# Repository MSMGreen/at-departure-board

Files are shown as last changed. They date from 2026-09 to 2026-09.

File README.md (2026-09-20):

# AT Departure Board



An ESP32 + 2.8" TFT that shows when the next bus and train actually leave, using
Auckland Transport's realtime feed.

Each service gets a lane, and the vehicle's position along its lane **is** its
time to arrival — it enters at the left twenty minutes out and pulls into the
stop as the countdown reaches zero. The point is that you can read it from
across a room without resolving any digits.

Status: live data, and configurable from a browser. The board fetches real AT
departures and realtime delays over WiFi/TLS, draws the board from them at
15 fps, and serves a setup page on your LAN for choosing stops and themes.
`DEMO_MODE` (synthetic departures, no network) still builds and is useful for a
no-key bring-up.

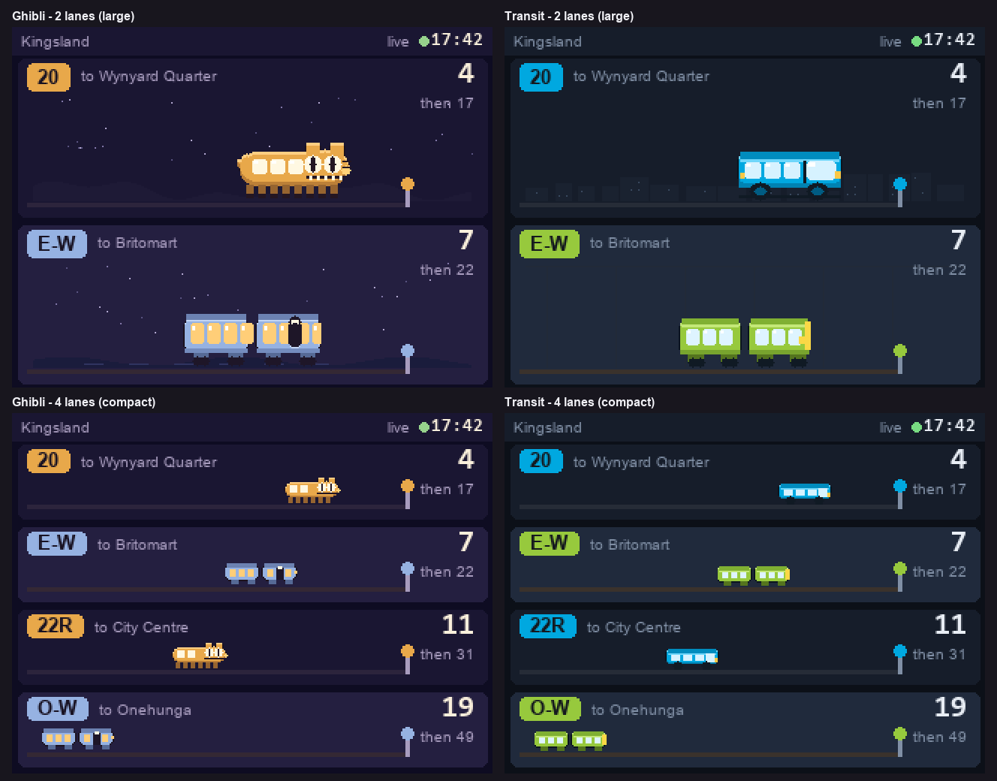
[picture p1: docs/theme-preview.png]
The board in two themes


## Try it without hardware

```bash
python -m pip install -r requirements-dev.txt
python tools/simulate.py --all --gif --show
```

Renders every board state to `tools/out/`, including the two that are easiest to
get wrong: 1am with nothing left tonight, and a cancelled service.

Two themes ship: `transit` and `ghibli`. Sprites come in two sizes — large art
at 1–2 watches, compact at 3–4, because a 40px vehicle does not fit a 55px lane.

```bash
python tools/simulate.py --scene two_up --theme ghibli
python tools/author_art.py               # regenerate the vehicle art
```

## Build one

Roughly an evening's work. **[docs/SETUP.md](docs/SETUP.md) is the full
walkthrough** — parts, wiring, flashing, and pointing it at your own stops. The
short version:

| Part | What to get |
|---|---|
| Board | Any standard **ESP32 DevKit (WROOM-32)**. The unit here is an ESP32-D0WD-V3: 4 MB flash, no PSRAM, CH340 USB-serial |
| Display | 2.8" 320x240 SPI panel, no touch needed — [the one used here](https://www.aliexpress.com/item/1005004557916570.html). Sold as ILI9341; the unit received was an **ST7789**, which the build flags already handle ([why](docs/hardware-notes.md)) |
| Case | Printed from `models/src/wedge.scad` in this repo — a raked wedge with a snap-on back. Dimensions for both boards in [docs/enclosure.md](docs/enclosure.md), assembly in [docs/assembly.md](docs/assembly.md) |
| Wiring | Nine jumper wires, or solder direct — table below |

You also need a free [AT developer API key](https://dev-portal.at.govt.nz/),
subscribed to **both** the GTFS and the Realtime products with the same key.

```bash
python -m pip install -r requirements-dev.txt
pio test -e native                       # firmware logic, on your PC (needs a C++ compiler)
cp src/secrets.example.h src/secrets.h   # then fill in WiFi + AT key
pio run -e esp32 -t upload               # the live board
pio run -e esp32_demo -t upload          # the demo: no WiFi, no API key
```

Before each upload: hold BOOT, tap EN, release BOOT. Auto-reset into the
bootloader does not work on these boards, and `platformio.ini` is set up
accordingly — see [docs/hardware-notes.md](docs/hardware-notes.md).

`platformio.ini` does not name a serial port, so PlatformIO auto-detects one. If
you have more than one board plugged in, pass it explicitly:

```bash
pio run -e esp32 -t upload --upload-port COM8      # /dev/ttyUSB0 on Linux
```

## Point it at your own stops

Once the board is on your WiFi, **open `http://<board-ip>/` in a browser** on the
same network. The setup page holds the location name, the theme, and up to four
watches. Save and restart writes them to NVS and reboots the board, which takes
a couple of seconds.

The board prints its IP to the serial monitor at boot (`pio device monitor`),
and it is also the new ESP32 client in your router's device list:

```
wifi: connected, ip 192.168.1.42 rssi -54
```

Each watch is four fields:

| Field | Meaning |
|---|---|
| Label | What the lane is called on the panel, e.g. `to Wynyard Quarter` (24 characters) |
| Stop code | The number on the pole, e.g. `8213`. **Check** confirms it against AT and shows you the stop's name |
| Route | A route to pin, e.g. `20`. Leave it empty for "any route that stops here" |
| Toward stop | The stop you are travelling *toward*, never a direction — direction is derived at every refresh ([why](docs/at-api-notes.md)) |

Pin a route when the stop also serves services you would never board: stop 8213
here is served by `22R`/`22N` as well, so that watch pins `20`. A stop served
only by routes you'd actually take can leave Route empty, as a rail watch does
— that is also what carries a rail watch through a line rename.

WiFi credentials and the API key are **not** in the setup page. They are
compiled in from `src/secrets.h`, which is gitignored, so changing networks
means a re-flash. `src/watch_config.h` holds the watches the board seeds NVS
with on its first boot, and is only consulted then.

### The setup page is unauthenticated

It is plain HTTP on port 80 with no password, so anyone on your LAN can change
the board's stops or reboot it. That is a deliberate trade for a device with no
keyboard on a home network — the page exposes no credentials and the board
stores nothing sensitive — but do not put this on an untrusted or guest
network, and do not forward a port to it.

## Development

```bash
python -m pytest                # the renderer and the tools
pio test -e native              # the firmware logic (needs a C++ compiler)
python tools/regolden.py        # ONLY when a render change is intended
python tools/export_sprites.py  # regenerate src/sprites.h after editing sprites
```

Renders are compared byte-exact against `tests/golden/`. A failing golden test
means the render changed — if that was intended, regenerate and commit the
goldens in the same commit as the change. Both suites run in CI on every push
and pull request. [CONTRIBUTING.md](CONTRIBUTING.md) has the rest.

## Layout

| Concern | File |
|---|---|
| Colour roles, AT `route_color` handling | `tools/board/palette.py` |
| Themes (palette, sprites, scenery) | `tools/board/themes/` |
| Vehicle art (parametric source) | `tools/author_art.py` |
| Pixel-art vehicles | `tools/board/sprites.py` |
| What the screen is showing | `tools/board/model.py` |
| Lane geometry, ETA → x position | `tools/board/layout.py` |
| Drawing | `tools/board/render.py` |
| The canonical board states | `tools/board/scenes.py` |
| Export sprites to C | `tools/export_sprites.py` |
| Firmware logic, no Arduino headers | `lib/core/src/` |
| Firmware wiring: network, portal, panel | `src/` |

Sprites are authored as role grids — `B` for body, `W` for window — rather than
literal colours, which is what lets one bus sprite render in whatever colour its
route is, and what lets a theme reinterpret every role at once. `src/sprites.h`
is generated from the same data and committed, so the firmware build never needs
Python.

Art is never typed by hand. Edit `tools/author_art.py`, which draws it
parametrically, then regenerate.

## Wiring

ESP32 dev board (WROOM-32) and a 2.8" 320x240 ST7789 SPI panel, no touch (sold as
ILI9341 — see `docs/hardware-notes.md`).

| Display | ESP32 |
|---|---|
| VCC | 3V3 |
| GND | GND |
| CS | GPIO15 |
| RESET | GPIO4 |
| DC / RS | GPIO2 |
| SDI / MOSI | GPIO23 |
| SCK | GPIO18 |
| LED | GPIO32 |
| SDO / MISO | GPIO19 |

Drive the backlight from GPIO32 rather than 3V3: there it is PWM-able, which is
what lets the panel dim rather than only switch off.

## Documentation

- [docs/SETUP.md](docs/SETUP.md) — build one from parts, start to finish.
- [docs/at-api-notes.md](docs/at-api-notes.md) — the AT API as it actually
  behaves, verified against live endpoints. **Read this before touching the
  network code**; it differs from AT's own documentation in five places,
  including one that would make the board re-resolve every stop every night.
- [docs/hardware-notes.md](docs/hardware-notes.md) — measured heap, the flashing
  dance, and why the panel is an ST7789.
- [docs/enclosure.md](docs/enclosure.md) — every dimension of the case and the
  two boards, and where each number came from.
- [docs/assembly.md](docs/assembly.md) — wiring and fitting it all into the
  printed case.
- [docs/design/](docs/design/) — the specs and implementation plans each
  feature was built from, kept as the record of why the code is shaped the way
  it is.

## Data and attribution

Departure data comes from [Auckland Transport's developer
API](https://dev-portal.at.govt.nz/) and is used under AT's developer terms —
check those terms before redistributing anything you build on it. The JSON under
`test/fixtures/` is captured AT API output, trimmed and used as test input.

This project is not affiliated with, endorsed by, or supported by Auckland
Transport.

## Licence

MIT — see `LICENSE`.

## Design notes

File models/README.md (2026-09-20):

# The enclosure

A raked wedge, 90 × 48 × 70 mm, in two printed parts: a body that holds the
panel and the DevKit, and a cover that snaps on the back.

```
src/wedge.scad          the model - every dimension is a named constant
build/wedge_body.stl    ready to slice
build/wedge_cover.stl   ready to slice
```

**To print one, take the two STLs in `build/`.** You do not need OpenSCAD for
that — they are committed for the same reason `src/sprites.h` is, so that
building the thing doesn't require the tool that generated it.

Print the body **on its back face**. The raked front then becomes a 15° overhang
that needs no support, and the face you look at comes out clean.

## To change it

`src/wedge.scad` is the source of truth. Case size, rake, wall thickness, panel
pocket, DevKit bay and every clearance are named constants at the top of the
file; change one and re-render:

```bash
openscad -o build/wedge_body.stl  -D 'part="body"'  src/wedge.scad
openscad -o build/wedge_cover.stl -D 'part="cover"' src/wedge.scad
```

Re-render and commit both STLs in the same commit as the `.scad` change, the
same rule the golden renders follow.

`python -m pytest tests/test_models.py` re-checks the clearances the design
depends on against the constants actually in the file, and that each part is
still a single manifold solid. It skips itself if OpenSCAD isn't installed.

## Where the numbers came from

[`../docs/enclosure.md`](../docs/enclosure.md) — every dimension of the case,
the panel and the DevKit, and the source of each (datasheet, measured, or
derived). [`../docs/assembly.md`](../docs/assembly.md) is how it goes together.
The reasoning behind the shape is in
[`../docs/design/specs/2026-09-20-enclosure-wedge-design.md`](../docs/design/specs/2026-09-20-enclosure-wedge-design.md).

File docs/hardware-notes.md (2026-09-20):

# Hardware and firmware notes — measured, not estimated

Everything here was measured on the actual board on 2026-09-15 by a throwaway
spike (`spike/heap/`, removed once it had answered its question — the code is
in the git history, last present at 026bc09). Where the design doc guessed a
number, the measured one is recorded next to it.

## The board

| | |
|---|---|
| Chip | ESP32-D0WD-V3 rev 3, dual core @ 240 MHz |
| Flash | 4 MB |
| PSRAM | **none** |
| USB-serial | CH340 (`1A86:7523`) |
| Shipped firmware | Espressif ESP-AT 1.1.2 — overwritten on first flash |

### Uploading needs the BOOT button held

Auto-reset into the bootloader does not work on this board: esptool resets the
chip but GPIO0 is not pulled low, so it boots the app and esptool reports
`Wrong boot mode detected (0x13)`.

What works reliably (2026-09-19): put the chip into download mode *first*, then
flash without letting esptool reset it.

1. Hold **BOOT**, press and release **EN**, then release **BOOT**. The chip now
   sits in the bootloader; the screen does not change.
2. `pio run -e esp32 -t upload`. `platformio.ini` sets
   `board_upload.before_reset = no_reset` and `upload_speed = 115200`, so
   esptool neither tries the broken auto-reset nor drops the link.

`--after hard_reset` via RTS *does* work, so the new firmware starts on its own.

Two ways it fails: `pio run -t upload` gives up after ~11 s, before a human can
do the buttons; and at **460800** baud the CH340 link drops right after the
baud switch (`No more data to read from the serial port`). Releasing BOOT
before EN also misses download mode (`No serial data received`).

Permanent fix if it becomes tiresome: a 1 µF capacitor between EN and GND.

## Memory — the design's budget holds with ~2x headroom

Paper estimate was ~85 KB of ~300 KB: 40 KB TLS + 35 KB sprite + 8 KB parser.

| Measurement | Value |
|---|---|
| Free heap at boot | 351,448 |
| **Largest contiguous block at boot** | **114,676** |
| 35,840-byte lane sprite | allocated, every byte touched |
| Free with sprite held | 315,592 |
| Free after WiFi up | ~209,000 |
| **TLS handshake cost** | **~44,000** (est. 40,000) |
| Free with sprite + TLS + parse live | ~157,000 |
| Largest block at that moment | 94,196 |
| **Lowest heap across a full run** | **150,932** |
| Leak check | returns to boot value exactly after every request |

### The per-lane sprite was necessary, not merely tidy

Free heap is ~351 KB but the **largest single block is ~114 KB**, because the
ESP32 heap is split across regions. A full-screen 320x240x16bpp framebuffer
needs **153,600 bytes contiguous** and therefore *cannot* be allocated at all.

The design's 320x56 per-lane sprite (35,840 bytes) was the only approach that
was ever going to work. Do not "optimise" it into a full framebuffer later.

## The display is an ST7789, not an ILI9341

The module is the common red "2.8\" TFT 240xRGBx320 V1.1" SPI board with an SD
slot and a touch footprint (touch unpopulated). It is sold as ILI9341, and the
design doc assumed that. The unit on hand has an **ST7789** controller. Found
by a bring-up spike (`spike/display/`, also removed — see the git history),
2026-09-19.

Wiring is exactly as in design doc §2, and it is right: nothing had to change.

TFT_eSPI configuration that works (build flags, no `User_Setup.h` edit):

```
-DUSER_SETUP_LOADED=1
-DST7789_DRIVER=1
-DTFT_RGB_ORDER=TFT_BGR
-DTFT_INVERSION_OFF=1
-DTFT_WIDTH=240  -DTFT_HEIGHT=320
-DTFT_MISO=19 -DTFT_MOSI=23 -DTFT_SCLK=18 -DTFT_CS=15 -DTFT_DC=2 -DTFT_RST=4
-DSPI_FREQUENCY=27000000
```

`setRotation(1)` and `(3)` give a clean 320x240 landscape; all four rotations
fill the glass edge to edge. The backlight on GPIO32 is driven HIGH by the app.

How each wrong setting looks, so it can be recognised again:

| Setting | Symptom |
|---|---|
| `ILI9341_DRIVER` | Landscape drawn un-rotated into 240 columns; the other 80 are static. Other rotations cut up / off-centre. Red and blue swapped. |
| ST7789, default inversion (ON) | Whole image a photo negative: black background shows white. |
| ST7789, default colour order (RGB) | Red and blue swapped. |
| Both defaults together | Red→yellow, green→magenta, blue→cyan, yellow→red. Looks random; it's inversion plus swap. |

The panel **does not answer reads**: RDDID (`0xD3`) returns `00 00 00` and
RDDST returns constant garbage. So the controller can't be detected in software;
identify it by rendering, as above. Don't build anything that depends on
reading back from the panel.

## Display performance

Measured on 2026-09-19 over a 225 s capture covering every scene in both themes,
SPI at 27 MHz (the default set in `platformio.ini`):

| Measurement | Value |
|---|---|
| SPI clock | 27 MHz |
| **Worst draw time per frame** | **59 ms** |
| Frame rate (all scenes) | 14.9–15.1 fps |
| **Lowest heap (min-ever)** | **311,588 bytes** |
| Largest contiguous block | 110,580 bytes |
| Flash used | 25.3% (331,741 of 1,310,720 bytes) |
| RAM | 6.9% |

The frame budget is 66 ms per frame at 15 fps; 59 ms leaves 7 ms of headroom.

The band renderer redraws the board in 48-row horizontal bands, each 320×48×2
bytes. That is **30,720 bytes per band** against the design spec's estimate of
35,840 (320×56), with **5 pushes per frame** to refresh the screen. This keeps
memory flat — no full-screen framebuffer.

SPI 40 MHz was not tried: 15 fps is met at 27 MHz and 40 MHz remains as headroom
for when WiFi and TLS run alongside.

### Double-precision sin() is software on this chip

The first measurement on 2026-09-19 showed the Ghibli theme at 96 ms per frame
(10.3 fps) in the 1–2 lane scenes, while transit ran at 54–57 ms. The cause:
`hill()` and `shore()` call `sin()` on doubles, and the ESP32's FPU is
single-precision only, so those calls are emulated in software. The band
renderer redraws each lane once per band, which meant about 3,000 software
`sin()` calls per frame.

Precomputing them into lookup tables (`hill_at` and `shore_at` in
`lib/core/src/shapes.cpp`, filled from the same functions so the values cannot
diverge) brought Ghibli to 58–59 ms per frame and unlocked 15 fps across all
scenes. The lesson: keep `double` maths out of the per-frame path.

## Flash is the tighter constraint

| Build | Flash used |
|---|---|
| Bare Arduino + heap probe | 265 KB (20%) |
| \+ WiFi, TLS, HTTPClient, ArduinoJson | **917 KB (70%)** |

70% of the default 1.31 MB app partition is gone before TFT_eSPI, the web
portal, or the sprite data exist. **The firmware will need a custom partition
table** — `huge_app.csv` or a hand-rolled one, noting OTA is a non-goal so a
single app partition is fine.

## The bug that would have shipped: chunked transfer-encoding

AT's GTFS API responds with `Transfer-Encoding: chunked`. The bytes on the wire
begin:

```
2561\r\n{"data":[{"type":"stoptrip", ...
```

The standard ESP32 idiom — `deserializeJson(doc, http.getStream())` — reads
`2561`, parses it as a valid JSON **number**, stops, and returns
`DeserializationError::Ok`. The document is a number, `doc["data"]` is null, and
the board shows **zero departures with no error, forever**.

The silent failure happens specifically **when parsing with an ArduinoJson
filter**, which the firmware always does (to keep the document small). With
ArduinoJson 7.4.3, measured across all three combinations:

| Parse | Body | Result |
|---|---|---|
| filtered | chunked | `Ok`, 0 rows — **silent** |
| filtered | clean (de-chunked) | `Ok`, 1 row |
| unfiltered | chunked | `InvalidInput` — loud |

Filtering is what turns a loud failure into a silent one: without a filter the
chunk-size token derails the parse enough to be rejected outright; with a
filter it's accepted as a lone number and the empty result looks like success.

Measured on hardware, same URL, same filter, back to back:

```
A. without de-chunking:  deserializeJson SUCCESS,  0 departures   <-- silent
B. with de-chunking:     deserializeJson SUCCESS, 19 departures
```

19 matches what `curl` returns for that URL. The fix is a small Stream wrapper
that unwraps chunk framing while keeping memory flat — it now lives in
`lib/core/src/dechunk.{h,cpp}`. `test/test_dechunk` pins both the bug (filtered
+ chunked without the wrapper) and the cure (filtered + chunked through it), so
neither regresses silently again.

### But the two AT APIs differ — branch, never assume

| API | Framing | `http.getSize()` |
|---|---|---|
| `gtfs/v3/...` | `Transfer-Encoding: chunked` | `-1` |
| `realtime/legacy/tripupdates` | `Content-Length` | e.g. `2176` |

De-chunking a **non**-chunked body is equally broken: the wrapper reads
`{"status"...` as a hex chunk header, gets 0, and declares the stream finished,
producing `EmptyInput`. Observed exactly that when the wrapper was applied
unconditionally.

So the client must branch on `http.getSize() < 0` at runtime rather than on
which endpoint it thinks it is calling.

## The `tripid` filter really is load-bearing

`GET /realtime/legacy/tripupdates` with **no** `?tripid=` returned
**766,473 bytes** — the whole Auckland network. Streaming it with an ArduinoJson
filter still drove free heap from ~160,000 down to **51,800**, largest block to
42,996, and ended in `IncompleteInput`.

With `?tripid=` and four trips the same endpoint returns **2,176 bytes**.

The design already said the filter was "load-bearing, not an optimisation".
That is now measured: unfiltered, the board comes within ~50 KB of the floor and
fails messily rather than cleanly.

## NTP and DST work

`configTzTime("NZST-12NZDT,M9.5.0,M4.1.0/3", "pool.ntp.org")` gave
`2026-09-15 20:42 NZST isdst=0` — correct. NZDT begins 27 September 2026; the
rule is in place and should flip on its own. Worth re-checking on the 28th.

## End-to-end, verified on hardware

The whole data path ran on the board on 2026-09-15 at 22:05, in one pass, with
the sprite held throughout:

```
A. stoptrips, no de-chunking              ->  0 departures   (silent failure)
B. stoptrips, de-chunked                  -> 11 departures
     22:04 O-W-201 dir 0 / 22:06 O-W-201 dir 1 / 22:26 E-W-201 dir 0
C. realtime ?tripid=, content-length      ->  4 entities
     delays -6, +16, -52, +66 seconds
```

The runtime branch picked `chunked -> de-chunking` for GTFS and
`content-length -> direct` for realtime within the same run, which is the
behaviour the firmware needs. Lowest heap across the whole pass: **151,032**.

Those delays are live: a train 52 s early and another 66 s late. Schedule alone
would have been wrong by over a minute in both directions.

## Live data on the board

Measured on the board on 2026-09-19, SPI at 27 MHz, WiFi and TLS live against
the real AT API:

| Measurement | Value |
|---|---|
| Frame rate | 15.1–15.2 fps |
| Worst draw time per frame | 55–57 ms (against a 66 ms budget) |
| Lowest heap (min-ever) | 94,944 bytes |
| Largest contiguous block | 94,196 bytes |
| Steady-state free heap | ~157 KB |
| Fetch task stack (core 0, 16,384 B) | 12,200 B free high-water mark — 4,184 B used at peak (16,384 − 12,200); the task performs the TLS handshakes, so this peak includes them |
| Live build flash | 75.6% (~990 KB of 1.31 MB) |
| Live build RAM | 25.8% |
| Demo build flash | 26.7% |

SPI stayed at 27 MHz: 15 fps held with the network running, so the 40 MHz
headroom noted above was not needed.

The lowest heap seen anywhere in this plan was **149,444 bytes**, during a TLS
handshake in `setup()` (the earlier self-check) — lower than the 157 KB
steady-state figure above but well clear of the ~95 KB floor seen during a live
fetch.

### TLS: the pinned root, and why the root

The board pins **DigiCert Global Root G2**, SHA256
`CB:3C:CB:B7:60:31:E5:E0:13:8F:8D:D3:9A:23:F9:DE:47:FF:C3:5E:43:C1:14:4C:EA:27:D4:6A:5A:B1:CB:5F`,
valid to 2038. The root is pinned rather than the leaf because the leaf
certificate expires in March 2027 — pinning it would mean the board silently
stops trusting AT's API a year from now. The root is stable for over a decade.

### NZ time rules live outside the standard library

Windows' UCRT (used for `pio test -e native`) mis-handles the POSIX TZ string:
it placed 2026-09-28 12:00 NZDT at 11:00 UTC, an hour wrong. So the NZ
DST rules are hand-implemented in `lib/core/src/nztime.cpp` rather than left to
the C library's TZ parsing.

### Flash headroom

Flash is at 75.6% for the live build. The portal (spec §3, not yet built) will
likely need `huge_app.csv` rather than the default partition table.

### First boot needs a wait for WiFi association

The first fetch attempt on first boot returned HTTP `-1` for both lookups: it
ran before WiFi association had completed. It succeeded once the code was
changed to wait for association rather than just for `WiFi.begin()` to
return.

## Still to verify on hardware

- PWM dimming driven by the app (the LEDC path itself is verified).
- The WiFi-outage path: pull WiFi, expect `stale Nm` with the last good data
  kept, the lanes dimmed and the vehicles still animating, then recovery without a reboot when
  WiFi returns. This has **not** been performed on hardware. The code paths
  were reviewed but not observed running.

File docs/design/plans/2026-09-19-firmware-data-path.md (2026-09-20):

# Firmware Data Path Implementation Plan

> **For agentic workers:** REQUIRED SUB-SKILL: Use superpowers:subagent-driven-development (recommended) or superpowers:executing-plans to implement this plan task-by-task. Steps use checkbox (`- [ ]`) syntax for tracking.

**Goal:** The board shows real Auckland Transport departures for the two
configured watches — schedule merged with live delays, correct at 1am and
across the DST change, honest when it cannot know.

**Architecture:** All decision logic is pure and natively tested in
`lib/core/`: NZ time arithmetic, a de-chunker, the AT response parsers and URL
builders, and the merge that turns a snapshot plus "now" into the `Board` the
renderer already draws. The device side is thin: one HTTPS client and one
FreeRTOS fetch task pinned to core 0, publishing a mutex-guarded snapshot. The
Arduino loop keeps drawing at 15 fps and never blocks on the network: it
rebuilds the `Board` from the snapshot and the current time every frame, which
is what makes the countdown tick smoothly between polls.

**Tech Stack:** PlatformIO, `espressif32@7.1.3` (Arduino core 2.0.17),
TFT_eSPI 2.5.43, ArduinoJson 7.4.3 (native and device), Unity, pytest.

**Spec:** `docs/design/specs/2026-09-06-at-departure-board-design.md`
(§3a derived direction, §5 data flow and time handling, §6 stop resolution,
§8 degradation). `docs/at-api-notes.md` is the verified record of how the API
actually behaves and outranks the spec where they differ.

## Scope

Second of three firmware plans. The display plan
(`2026-09-19-firmware-display.md`) is merged.

**In scope:** WiFi, NTP, TLS with a pinned root CA, stop/route resolution,
schedule fetch, derived direction, realtime delays, the error and stale
surfaces, and a live frame loop.

**Not in scope, deliberately:**
- The captive portal and NVS config (plan 3). Until then WiFi credentials and
  the API key come from a git-ignored `src/secrets.h`, and the watch list from
  a committed `src/watch_config.h`. The spec's "no secrets in the repo, no
  recompile to change a stop" is only met when plan 3 lands.
- Brightness that follows use, and quiet hours (plan 3). `dimmed` stays false.
- Caching resolved stop ids in NVS (plan 3). They are resolved once per boot,
  four requests, and held in RAM.
- Spec §7's "next service's day and time in text" for the empty state. It needs
  a search beyond the fetch window; the board keeps showing `none tonight`.

## Global Constraints

- **The Python simulator is the source of truth for anything the screen
  shows.** A new display field is added to `tools/board/model.py` and
  `render.py` with goldens first, then regenerated into C. The firmware never
  grows a display concept the simulator does not have.
- **Never block the render loop on the network.** Fetching runs in a FreeRTOS
  task pinned to core 0; the Arduino loop only reads a published snapshot.
- **Never show a time the board cannot prove.** A watch whose direction cannot
  be derived shows `check config` and no times (spec §3a).
- **A `stoptrips` 404 is an empty window, not an error** (`docs/at-api-notes.md`).
  Only a 404 from `/stops/{id}` would invalidate a stop id, and this plan never
  calls that endpoint.
- **`filter[start_hour]` must be 1..23.** `start_hour=0` returns
  400 `Invalid Request` — verified live on 2026-09-19.
- **Branch on `http.getSize() < 0` at runtime** to decide whether to de-chunk.
  The GTFS API is chunked, the realtime API is not, and getting this wrong
  fails silently in both directions (`docs/hardware-notes.md`).
- **The `tripid` filter is inexact.** Re-filter returned trip ids against the
  requested set.
- **Delay comes from trip-level `trip_update.delay`**, preferring
  `stop_time_update.departure.delay` only when its `stop_id` is ours.
- **TLS verifies against the pinned DigiCert Global Root G2.**
  `setInsecure()` must not appear in `src/`.
- Pure code in `lib/core/` includes no Arduino or TFT headers, and builds under
  `native`. ArduinoJson is allowed there (it is portable and already used by
  both envs).
- Python `round()` is half-to-even (`nearbyint`), `int()` truncates (a C cast),
  PIL boxes are inclusive. Keep new ports consistent with these.
- Every `Board` the renderer sees is built by `build_board`, never assembled ad
  hoc in `src/`.
- Native tests need GCC on PATH. A fresh shell has it; an older one needs
  `export PATH="<your mingw64>/bin:$PATH"`.
- Uploading needs a human: hold BOOT, press and release EN, release BOOT, then
  `pio run -e <env> -t upload`. The controller does every flash, serial capture
  and on-glass check.
- `python -m pytest` and `pio test -e native` stay green after every task.

## File Structure

| File | Responsibility |
|---|---|
| `lib/core/src/nztime.{h,cpp}` | Civil-date arithmetic, NZ DST rules, GTFS time parsing |
| `lib/core/src/dechunk.{h,cpp}` | Pure HTTP chunked-transfer unwrapper, an ArduinoJson input |
| `lib/core/src/at_api.{h,cpp}` | AT URLs, ArduinoJson filters, response parsers into structs |
| `lib/core/src/live.{h,cpp}` | Watch config, snapshot types, direction derivation, realtime merge, `build_board` |
| `src/secrets.example.h` | Template for the git-ignored `src/secrets.h` |
| `src/watch_config.h` | The two watches and the location label (committed; no secrets) |
| `src/at_ca.h` | Pinned DigiCert Global Root G2 PEM |
| `src/at_client.{h,cpp}` | One HTTPS GET: CA, key header, chunked branch, filtered parse |
| `src/fetcher.{h,cpp}` | The core-0 task: resolve, schedule, direction, realtime, backoff, publish |
| `src/main.cpp` | Frame loop; demo or live board source |
| `test/test_nztime,test_dechunk,test_at_api,test_live/` | Native suites |

---

### Task 1: A location and a per-watch message, Python first

**Files:**
- Modify: `tools/board/model.py`, `tools/board/render.py`, `tools/board/scenes.py`
- Modify: `tests/test_model.py`, `tests/test_render.py`
- Create: `tests/golden/check_config.png` (generated)
- Modify: `tools/export_sprites.py`, `lib/core/src/demo.h`, `lib/core/src/demo.cpp`, `lib/core/src/model.h`, `lib/core/src/model.cpp`, `src/ui.cpp`, `test/test_model/test_main.cpp`, `test/test_demo/test_main.cpp`
- Regenerate: `lib/core/src/scenes_data.h`

**Interfaces:**
- Produces (Python): `Watch.message: Optional[str] = None`, `Board.location: str = "Kingsland"`
- Produces (C): `Board.location[24]`, `Watch.message[32]`,
  `void board_set_location(Board*, const char*)`, `void watch_set_message(Watch*, const char*)`
- Rule, both sides: a watch with a message shows no times and a parked vehicle.

Why: the data path needs to say "check config" and "check API key" on a lane
(spec §8), and the status bar's location stops being hardcoded. Per the global
constraint, the simulator gets it first.

- [ ] **Step 1: Write the failing Python tests.** Append to `tests/test_model.py`:

```python
def test_a_watch_has_no_message_by_default():
    assert Watch(badge="20", headsign="x", kind="bus").message is None

def test_a_board_defaults_to_the_kingsland_location():
    assert Board([Watch(badge="20", headsign="x", kind="bus")], "17:42").location == "Kingsland"
```

Append to `tests/test_render.py` (it already imports `render`, `scenes`; add
`from tools.board.model import Board, Departure, Watch` if not present):

```python
def test_a_watch_with_a_message_never_shows_a_time():
    # Spec 3a: a watch that cannot prove which way it points must not display
    # a time. Rendering must therefore ignore departures entirely.
    with_deps = Board([Watch(departures=[Departure(240, live=True)],
                             message="check config", **scenes.BUS20)], "17:42")
    without = Board([Watch(departures=[], message="check config", **scenes.BUS20)], "17:42")
    assert render.render(with_deps, t=0.0).tobytes() == render.render(without, t=0.0).tobytes()

def test_the_message_is_actually_drawn():
    plain = Board([Watch(departures=[], **scenes.BUS20)], "17:42")
    noisy = Board([Watch(departures=[], message="check config", **scenes.BUS20)], "17:42")
    assert render.render(plain, t=0.0).tobytes() != render.render(noisy, t=0.0).tobytes()

def test_the_location_is_drawn_in_the_status_bar():
    here = Board([Watch(departures=[], **scenes.BUS20)], "17:42")
    there = Board([Watch(departures=[], **scenes.BUS20)], "17:42", location="Ponsonby")
    assert render.render(here, t=0.0).tobytes() != render.render(there, t=0.0).tobytes()
```

- [ ] **Step 2: Run them to see them fail**

Run: `python -m pytest tests/test_model.py tests/test_render.py -q`
Expected: failures — `TypeError: __init__() got an unexpected keyword argument 'message'` / `'location'`.

- [ ] **Step 3: Add the fields in `tools/board/model.py`.** In `Watch`, after
`route_color`:

```python
    # Set when the board cannot honestly show times for this watch (spec 8).
    # A watch with a message shows no departures at all.
    message: Optional[str] = None
```

In `Board`, after `theme`:

```python
    location: str = "Kingsland"
```

- [ ] **Step 4: Draw them in `tools/board/render.py`.** In `_status_bar`,
replace the hardcoded label:

```python
    d.text((6, mid), board.location, font=reg(11), fill=th.colour("dim"), anchor="lm")
```

In `_lane`, replace `nxt = watch.next` with:

```python
    # A watch carrying a message must not show a time, however many
    # departures it happens to hold.
    nxt = None if watch.message else watch.next
```

and replace the `if nxt is None:` branch of the times block with:

```python
    if watch.message:
        d.text(ln.minutes_xy, "--", font=mono(20), fill=th.colour("dim"), anchor="ra")
        d.text(ln.following_xy, watch.message, font=reg(9),
               fill=th.colour("warn"), anchor="ra")
    elif nxt is None:
        d.text(ln.minutes_xy, "--", font=mono(20), fill=th.colour("dim"), anchor="ra")
        d.text(ln.following_xy, "none tonight", font=reg(9),
               fill=th.colour("dim"), anchor="ra")
```

- [ ] **Step 5: Add the scene.** At the end of `SCENES` in `tools/board/scenes.py`:

```python
    # Direction could not be derived (spec 3a). The departures are deliberately
    # present: a watch that cannot prove its direction must show none of them.
    "check_config": Board([
        Watch(departures=[Departure(240, live=True), Departure(1020)],
              message="check config", **BUS20),
        Watch(departures=[Departure(420, live=True)], **TRAIN),
    ], "17:42"),
```

- [ ] **Step 6: Run the Python tests, then freeze the new golden**

Run: `python -m pytest -q`
Expected: the five new tests pass; `test_matches_golden[check_config]` fails
with "no golden for 'check_config'".
Run: `python tools/regolden.py`
Run: `git status --short tests/golden`
Expected: exactly one new file, `tests/golden/check_config.png`. If any
existing golden changed, stop and report — the port must not alter existing
renders.
Run: `python -m pytest -q`
Expected: all pass.

- [ ] **Step 7: Mirror the fields in C.** In `lib/core/src/model.h`, add to
`Watch` after `route_color`:

```cpp
  // Set when the board cannot honestly show times for this watch (spec 8).
  // A watch with a message shows no departures at all.
  char message[32];
```

add to `Board` after `theme`:

```cpp
  char location[24];
```

and declare beneath `watch_init`:

```cpp
void watch_set_message(Watch* w, const char* message);  // null or "" clears it
void board_set_location(Board* b, const char* location);
```

In `lib/core/src/model.cpp` implement both with the existing `copy_text`
helper (`watch_set_message(w, nullptr)` must leave `w->message[0] == '\0'`).

- [ ] **Step 8: Carry them through the exporter.** In `tools/export_sprites.py`
`render_scenes_header`, emit `location` after the clock for a scene, and
`message` after `route_color` for a watch:

```python
        parts.append(f"    {{{_cstr(name)}, {_cstr(board.clock)}, {_cstr(board.location)}, "
                     f"{board.stale_s}, {_bool(board.dimmed)}, {len(board.watches)}, {{")
```

```python
            parts.append(f"        {{{_cstr(w.badge)}, {_cstr(w.headsign)}, "
                         f"{KIND_CONST[w.kind]}, {_cstr(w.route_color)}, {_cstr(w.message)}, "
                         f"{len(w.departures)}, {{{deps}}}}},")
```

In `lib/core/src/demo.h`, add `const char* location;` to `Scene` after `clock`,
and `const char* message;` to `SceneWatch` after `route_color`. In
`lib/core/src/demo.cpp` `board_from_scene`, after `watch_init(...)` add
`watch_set_message(&w, sw.message);`, and after the clock copy add
`board_set_location(&b, s.location);`.

- [ ] **Step 9: Honour the message on the panel.** In `src/ui.cpp`: delete the
`LOCATION` constant and use `b.location` in `status_bar`; in `times()` replace
the `nxt == nullptr` early branch with:

```cpp
  const Departure* nxt = w.message[0] != '\0' ? nullptr : w.next();
  if (nxt == nullptr) {
    p.text("--", ln.minutes_x, ln.minutes_y, TR_DATUM, FONT_MINUTES, dim);
    const bool has_message = w.message[0] != '\0';
    p.text(has_message ? w.message : "none tonight", ln.following_x, ln.following_y,
           TR_DATUM, FONT_SMALL, has_message ? th.colours[C_WARN] : dim);
    return;
  }
```

(delete the old `const Departure* nxt = w.next();` line that preceded it), and
in `vehicle()` change the first line to the same guard:

```cpp
  const Departure* nxt = w.message[0] != '\0' ? nullptr : w.next();
```

- [ ] **Step 10: Write the failing C tests.** Add to `test/test_model/test_main.cpp`
(and register with `RUN_TEST`):

```cpp
void test_message_and_location_round_trip_and_truncate() {
  Watch w;
  watch_init(&w, "20", "x", Kind::Bus, nullptr);
  TEST_ASSERT_EQUAL_STRING("", w.message);
  watch_set_message(&w, "check config");
  TEST_ASSERT_EQUAL_STRING("check config", w.message);
  watch_set_message(&w, nullptr);
  TEST_ASSERT_EQUAL_STRING("", w.message);
  watch_set_message(&w, "a message far longer than the thirty-two bytes we keep for it");
  TEST_ASSERT_EQUAL_size_t(sizeof w.message - 1, strlen(w.message));

  Board b;
  memset(&b, 0, sizeof b);
  board_set_location(&b, "Kingsland");
  TEST_ASSERT_EQUAL_STRING("Kingsland", b.location);
}
```

In `test/test_demo/test_main.cpp`: change the scene count assertion to 9, add
`TEST_ASSERT_EQUAL_STRING("check_config", demo_scene(8).name);`, replace the
hardcoded `8 * DEMO_SCENE_MS` in the theme-cycle test with
`demo_scene_count() * DEMO_SCENE_MS`, and add:

```cpp
void test_the_check_config_scene_carries_its_message_and_location() {
  const Board b = demo_board(8 * DEMO_SCENE_MS);
  TEST_ASSERT_EQUAL_STRING("check config", b.watches[0].message);
  TEST_ASSERT_EQUAL_STRING("", b.watches[1].message);
  TEST_ASSERT_EQUAL_STRING("Kingsland", b.location);
}
```

- [ ] **Step 11: Regenerate and run everything**

Run: `python tools/export_sprites.py`
Run: `git diff --ignore-cr-at-eol --stat -- src/sprites.h lib/core/src/theme_data.h`
Expected: empty. If so, `git checkout -- src/sprites.h lib/core/src/theme_data.h`.
Run: `python -m pytest -q` → all pass.
Run: `pio test -e native` → all suites pass.
Run: `pio run -e esp32` → [SUCCESS].

- [ ] **Step 12: Commit**

```bash
git add tools/board/model.py tools/board/render.py tools/board/scenes.py tests/ tools/export_sprites.py lib/core/src/ src/ui.cpp test/
git commit -m "Give a board a location and a watch a message, simulator first

The data path needs lanes that can say 'check config' and 'check API key'
without showing a time (spec 3a and 8), and a status bar whose location is
not hardcoded. Both start in the Python, with a golden, then regenerate."
```

---

### Task 2: NZ time

**Files:**
- Create: `lib/core/src/nztime.h`, `lib/core/src/nztime.cpp`
- Test: `test/test_nztime/test_main.cpp`

**Interfaces:**
- Produces:
  - `struct CivilDate { int y, m, d; };`
  - `struct LocalTime { int y, m, d, hour, min, sec, offset_s; };`
  - `int64_t days_from_civil(int y, int m, int d);` / `CivilDate civil_from_days(int64_t z);`
  - `int nz_offset_s(int64_t epoch);` → 43200 or 46800
  - `LocalTime nz_local(int64_t epoch);`
  - `int64_t nz_epoch(int y, int m, int d, int32_t secs_of_day);`
  - `bool parse_gtfs_time(const char* s, int32_t* secs);` accepts hours 0..47
  - `bool parse_iso_date(const char* s, CivilDate* out);`
  - `int64_t gtfs_epoch(CivilDate service_date, int32_t secs);`
  - `void format_clock(int64_t epoch, char* out, size_t n);` → `"17:42"`
  - `void format_iso_date(CivilDate d, char* out, size_t n);` → `"2026-09-19"`

The host C runtime cannot be used for this: with `TZ=NZST-12NZDT,M9.5.0,M4.1.0/3`
set, Windows' UCRT placed 2026-09-28 12:00 NZDT at 11:00 UTC instead of the
correct 23:00 UTC on the 27th. So the rules are ours, in pure code, identical on
both sides. Expected values below come from Python's `zoneinfo`
(`Pacific/Auckland`, tzdata 2025.2).

NZ rules: NZDT (UTC+13) from 02:00 NZST on the **last Sunday in September** to
03:00 NZDT on the **first Sunday in April**; NZST (UTC+12) otherwise.

GTFS service-day rule: a time is elapsed seconds from **noon minus 12 hours**,
in absolute time, so noon always maps to noon even on a DST day.

- [ ] **Step 1: Write the failing test** at `test/test_nztime/test_main.cpp`

```cpp
#include <string.h>
#include <unity.h>

#include "nztime.h"

void setUp() {}
void tearDown() {}

void test_civil_days_round_trip() {
  TEST_ASSERT_EQUAL_INT64(0, days_from_civil(1970, 1, 1));
  TEST_ASSERT_EQUAL_INT64(20715, days_from_civil(2026, 9, 19));
  const CivilDate d = civil_from_days(20715);
  TEST_ASSERT_EQUAL_INT(2026, d.y);
  TEST_ASSERT_EQUAL_INT(9, d.m);
  TEST_ASSERT_EQUAL_INT(19, d.d);
  for (int64_t z = -1000; z < 30000; z += 97) {
    const CivilDate c = civil_from_days(z);
    TEST_ASSERT_EQUAL_INT64(z, days_from_civil(c.y, c.m, c.d));
  }
}

void test_dst_starts_on_the_last_sunday_in_september() {
  TEST_ASSERT_EQUAL_INT(43200, nz_offset_s(1790431199));  // 2026-09-27 01:59:59 NZST
  TEST_ASSERT_EQUAL_INT(46800, nz_offset_s(1790431200));  // 03:00:00 NZDT
}

void test_dst_ends_on_the_first_sunday_in_april() {
  TEST_ASSERT_EQUAL_INT(46800, nz_offset_s(1806760799));  // 2027-04-04 02:59:59 NZDT
  TEST_ASSERT_EQUAL_INT(43200, nz_offset_s(1806760800));  // 02:00:00 NZST
}

void test_offsets_in_the_middle_of_each_season() {
  TEST_ASSERT_EQUAL_INT(46800, nz_offset_s(1799953200));  // 2027-01-15 08:00 NZDT
  TEST_ASSERT_EQUAL_INT(43200, nz_offset_s(1782849600));  // 2026-07-01 08:00 NZST
}

void test_local_breakdown() {
  const LocalTime t = nz_local(1789796520);
  TEST_ASSERT_EQUAL_INT(2026, t.y);
  TEST_ASSERT_EQUAL_INT(9, t.m);
  TEST_ASSERT_EQUAL_INT(19, t.d);
  TEST_ASSERT_EQUAL_INT(17, t.hour);
  TEST_ASSERT_EQUAL_INT(42, t.min);
  TEST_ASSERT_EQUAL_INT(0, t.sec);
  TEST_ASSERT_EQUAL_INT(43200, t.offset_s);

  const LocalTime u = nz_local(1790550000);  // 2026-09-28 12:00 NZDT
  TEST_ASSERT_EQUAL_INT(28, u.d);
  TEST_ASSERT_EQUAL_INT(12, u.hour);
  TEST_ASSERT_EQUAL_INT(46800, u.offset_s);
}

void test_local_to_epoch_round_trips() {
  TEST_ASSERT_EQUAL_INT64(1789796520, nz_epoch(2026, 9, 19, 17 * 3600 + 42 * 60));
  TEST_ASSERT_EQUAL_INT64(1790550000, nz_epoch(2026, 9, 28, 12 * 3600));
}

void test_local_to_epoch_at_the_spring_gap_and_autumn_overlap() {
  // 02:30 on 2026-09-27 never happens; resolve it with the offset in force
  // before the jump, as Python's fold=0 does: the instant is 03:30 NZDT.
  TEST_ASSERT_EQUAL_INT64(1790433000, nz_epoch(2026, 9, 27, 2 * 3600 + 1800));
  // 02:30 on 2027-04-04 happens twice; take the first (still NZDT).
  TEST_ASSERT_EQUAL_INT64(1806759000, nz_epoch(2027, 4, 4, 2 * 3600 + 1800));
}

void test_parse_gtfs_time_including_after_midnight() {
  int32_t s = -1;
  TEST_ASSERT_TRUE(parse_gtfs_time("15:04:07", &s));
  TEST_ASSERT_EQUAL_INT32(15 * 3600 + 4 * 60 + 7, s);
  TEST_ASSERT_TRUE(parse_gtfs_time("25:10:00", &s));
  TEST_ASSERT_EQUAL_INT32(25 * 3600 + 600, s);
  TEST_ASSERT_TRUE(parse_gtfs_time("00:00:00", &s));
  TEST_ASSERT_EQUAL_INT32(0, s);
  TEST_ASSERT_FALSE(parse_gtfs_time("", &s));
  TEST_ASSERT_FALSE(parse_gtfs_time("15:04", &s));
  TEST_ASSERT_FALSE(parse_gtfs_time("aa:bb:cc", &s));
  TEST_ASSERT_FALSE(parse_gtfs_time("48:00:00", &s));
  TEST_ASSERT_FALSE(parse_gtfs_time("15:60:00", &s));
}

void test_parse_iso_date() {
  CivilDate d{};
  TEST_ASSERT_TRUE(parse_iso_date("2026-09-13", &d));
  TEST_ASSERT_EQUAL_INT(2026, d.y);
  TEST_ASSERT_EQUAL_INT(9, d.m);
  TEST_ASSERT_EQUAL_INT(13, d.d);
  TEST_ASSERT_FALSE(parse_iso_date("2026-13-01", &d));
  TEST_ASSERT_FALSE(parse_iso_date("nope", &d));
}

void test_gtfs_epoch_uses_noon_minus_twelve_hours() {
  TEST_ASSERT_EQUAL_INT64(1789268647, gtfs_epoch({2026, 9, 13}, 15 * 3600 + 4 * 60 + 7));
  // 25:10 on the 19th is 01:10 on the 20th.
  TEST_ASSERT_EQUAL_INT64(1789823400, gtfs_epoch({2026, 9, 19}, 25 * 3600 + 600));
  // On the day DST starts, noon is still noon...
  TEST_ASSERT_EQUAL_INT64(1790463600, gtfs_epoch({2026, 9, 27}, 12 * 3600));
  // ...but 01:00 is 00:00, because an hour of that day does not exist.
  TEST_ASSERT_EQUAL_INT64(1790424000, gtfs_epoch({2026, 9, 27}, 3600));
  // And on the day it ends, 01:00 is 02:00 for the same reason in reverse.
  TEST_ASSERT_EQUAL_INT64(1806757200, gtfs_epoch({2027, 4, 4}, 3600));
}

void test_formatting() {
  char buf[16];
  format_clock(1789796520, buf, sizeof buf);
  TEST_ASSERT_EQUAL_STRING("17:42", buf);
  format_iso_date({2026, 9, 5}, buf, sizeof buf);
  TEST_ASSERT_EQUAL_STRING("2026-09-05", buf);
}

int main(int, char**) {
  UNITY_BEGIN();
  RUN_TEST(test_civil_days_round_trip);
  RUN_TEST(test_dst_starts_on_the_last_sunday_in_september);
  RUN_TEST(test_dst_ends_on_the_first_sunday_in_april);
  RUN_TEST(test_offsets_in_the_middle_of_each_season);
  RUN_TEST(test_local_breakdown);
  RUN_TEST(test_local_to_epoch_round_trips);
  RUN_TEST(test_local_to_epoch_at_the_spring_gap_and_autumn_overlap);
  RUN_TEST(test_parse_gtfs_time_including_after_midnight);
  RUN_TEST(test_parse_iso_date);
  RUN_TEST(test_gtfs_epoch_uses_noon_minus_twelve_hours);
  RUN_TEST(test_formatting);
  return UNITY_END();
}
```

- [ ] **Step 2: Run it to see it fail**

Run: `pio test -e native -f test_nztime`
Expected: build error, `nztime.h: No such file or directory`.

- [ ] **Step 3: Create `lib/core/src/nztime.h`**

```cpp
#pragma once
#include <stddef.h>
#include <stdint.h>

// Pacific/Auckland without the C library. Windows' UCRT mis-handles the POSIX
// TZ string (it placed 2026-09-28 12:00 NZDT at 11:00 UTC), so the rules live
// here and behave identically on the device and in the native tests.
//
// NZDT (UTC+13) runs from 02:00 NZST on the last Sunday in September to
// 03:00 NZDT on the first Sunday in April. NZST (UTC+12) otherwise.

struct CivilDate {
  int y, m, d;
};

struct LocalTime {
  int y, m, d, hour, min, sec;
  int offset_s;  // 43200 (NZST) or 46800 (NZDT)
};

// Days since 1970-01-01 (Howard Hinnant's civil algorithms).
int64_t days_from_civil(int y, int m, int d);
CivilDate civil_from_days(int64_t z);

int nz_offset_s(int64_t epoch);
LocalTime nz_local(int64_t epoch);

// Wall-clock to epoch. A time in the spring gap resolves with the offset in
// force before the jump; an ambiguous autumn time takes the first occurrence.
int64_t nz_epoch(int y, int m, int d, int32_t secs_of_day);

// "HH:MM:SS", hours 0..47 - GTFS uses 25:10:00 for 01:10 the next day.
bool parse_gtfs_time(const char* s, int32_t* secs);
bool parse_iso_date(const char* s, CivilDate* out);

// GTFS measures a departure as elapsed seconds from noon minus 12 hours of the
// service day, in absolute time, so noon stays noon when the clocks change.
int64_t gtfs_epoch(CivilDate service_date, int32_t secs);

void format_clock(int64_t epoch, char* out, size_t n);      // "17:42"
void format_iso_date(CivilDate d, char* out, size_t n);     // "2026-09-19"
```

- [ ] **Step 4: Create `lib/core/src/nztime.cpp`**

```cpp
#include "nztime.h"

#include <stdio.h>
#include <string.h>

namespace {

constexpr int64_t DAY = 86400;
constexpr int NZST = 12 * 3600;
constexpr int NZDT = 13 * 3600;

// 0 = Sunday.
int weekday_from_days(int64_t z) { return static_cast<int>((z + 4) % 7 + 7) % 7; }

// Day-of-month of the last `weekday` in a month.
int last_weekday_of(int y, int m, int weekday) {
  static const int mdays[] = {31, 28, 31, 30, 31, 30, 31, 31, 30, 31, 30, 31};
  int last = mdays[m - 1];
  if (m == 2 && ((y % 4 == 0 && y % 100 != 0) || y % 400 == 0)) last = 29;
  const int wd = weekday_from_days(days_from_civil(y, m, last));
  return last - ((wd - weekday + 7) % 7);
}

int first_weekday_of(int y, int m, int weekday) {
  const int wd = weekday_from_days(days_from_civil(y, m, 1));
  return 1 + ((weekday - wd + 7) % 7);
}

// DST starts 02:00 NZST on the last Sunday in September.
int64_t dst_start(int y) {
  return days_from_civil(y, 9, last_weekday_of(y, 9, 0)) * DAY + 2 * 3600 - NZST;
}

// DST ends 03:00 NZDT on the first Sunday in April.
int64_t dst_end(int y) {
  return days_from_civil(y, 4, first_weekday_of(y, 4, 0)) * DAY + 3 * 3600 - NZDT;
}

}  // namespace

int64_t days_from_civil(int y, int m, int d) {
  y -= m <= 2;
  const int64_t era = (y >= 0 ? y : y - 399) / 400;
  const unsigned yoe = static_cast<unsigned>(y - era * 400);
  const unsigned doy = (153 * (m + (m > 2 ? -3 : 9)) + 2) / 5 + d - 1;
  const unsigned doe = yoe * 365 + yoe / 4 - yoe / 100 + doy;
  return era * 146097 + static_cast<int64_t>(doe) - 719468;
}

CivilDate civil_from_days(int64_t z) {
  z += 719468;
  const int64_t era = (z >= 0 ? z : z - 146096) / 146097;
  const unsigned doe = static_cast<unsigned>(z - era * 146097);
  const unsigned yoe = (doe - doe / 1460 + doe / 36524 - doe / 146096) / 365;
  const int64_t y = static_cast<int64_t>(yoe) + era * 400;
  const unsigned doy = doe - (365 * yoe + yoe / 4 - yoe / 100);
  const unsigned mp = (5 * doy + 2) / 153;
  const unsigned d = doy - (153 * mp + 2) / 5 + 1;
  const unsigned m = mp + (mp < 10 ? 3 : -9);
  return {static_cast<int>(y + (m <= 2)), static_cast<int>(m), static_cast<int>(d)};
}

int nz_offset_s(int64_t epoch) {
  const CivilDate utc = civil_from_days(epoch >= 0 ? epoch / DAY : (epoch - DAY + 1) / DAY);
  return (epoch >= dst_start(utc.y) || epoch < dst_end(utc.y)) ? NZDT : NZST;
}

LocalTime nz_local(int64_t epoch) {
  const int offset = nz_offset_s(epoch);
  const int64_t local = epoch + offset;
  int64_t days = local / DAY;
  int64_t rem = local % DAY;
  if (rem < 0) {
    rem += DAY;
    days -= 1;
  }
  const CivilDate c = civil_from_days(days);
  LocalTime t{};
  t.y = c.y;
  t.m = c.m;
  t.d = c.d;
  t.hour = static_cast<int>(rem / 3600);
  t.min = static_cast<int>((rem % 3600) / 60);
  t.sec = static_cast<int>(rem % 60);
  t.offset_s = offset;
  return t;
}

int64_t nz_epoch(int y, int m, int d, int32_t secs_of_day) {
  const int64_t wall = days_from_civil(y, m, d) * DAY + secs_of_day;
  const int64_t as_dst = wall - NZDT;
  if (nz_offset_s(as_dst) == NZDT) return as_dst;  // also picks the first of an
                                                   // ambiguous autumn pair
  const int64_t as_std = wall - NZST;
  if (nz_offset_s(as_std) == NZST) return as_std;
  return as_std;  // spring gap: the wall time never happens
}

bool parse_gtfs_time(const char* s, int32_t* secs) {
  if (s == nullptr || strlen(s) != 8 || s[2] != ':' || s[5] != ':') return false;
  int v[3] = {0, 0, 0};
  for (int part = 0; part < 3; part++) {
    const char* p = s + part * 3;
    if (p[0] < '0' || p[0] > '9' || p[1] < '0' || p[1] > '9') return false;
    v[part] = (p[0] - '0') * 10 + (p[1] - '0');
  }
  if (v[0] > 47 || v[1] > 59 || v[2] > 59) return false;
  *secs = v[0] * 3600 + v[1] * 60 + v[2];
  return true;
}

bool parse_iso_date(const char* s, CivilDate* out) {
  if (s == nullptr || strlen(s) != 10 || s[4] != '-' || s[7] != '-') return false;
  int y = 0;
  for (int i = 0; i < 4; i++) {
    if (s[i] < '0' || s[i] > '9') return false;
    y = y * 10 + (s[i] - '0');
  }
  int part[2] = {0, 0};
  for (int k = 0; k < 2; k++) {
    const char* p = s + 5 + k * 3;
    if (p[0] < '0' || p[0] > '9' || p[1] < '0' || p[1] > '9') return false;
    part[k] = (p[0] - '0') * 10 + (p[1] - '0');
  }
  if (part[0] < 1 || part[0] > 12 || part[1] < 1 || part[1] > 31) return false;
  *out = {y, part[0], part[1]};
  return true;
}

int64_t gtfs_epoch(CivilDate service_date, int32_t secs) {
  const int64_t noon = nz_epoch(service_date.y, service_date.m, service_date.d, 12 * 3600);
  return noon - 12 * 3600 + secs;
}

void format_clock(int64_t epoch, char* out, size_t n) {
  const LocalTime t = nz_local(epoch);
  snprintf(out, n, "%02d:%02d", t.hour, t.min);
}

void format_iso_date(CivilDate d, char* out, size_t n) {
  snprintf(out, n, "%04d-%02d-%02d", d.y, d.m, d.d);
}
```

- [ ] **Step 5: Run it to see it pass**

Run: `pio test -e native -f test_nztime`
Expected: `11 test cases: 11 succeeded`.

- [ ] **Step 6: Commit**

```bash
git add lib/core/src/nztime.h lib/core/src/nztime.cpp test/test_nztime/test_main.cpp
git commit -m "Implement Pacific/Auckland ourselves, because the host libc gets it wrong

Windows' UCRT placed 2026-09-28 12:00 NZDT at 11:00 UTC with the POSIX TZ
string the spike used. The rules are 40 lines; the values are pinned against
Python's zoneinfo, including both DST transitions and the GTFS noon-minus-12
service-day rule that keeps noon at noon when the clocks move."
```

---

### Task 3: The de-chunker, as pure code

**Files:**
- Create: `lib/core/src/dechunk.h`, `lib/core/src/dechunk.cpp`
- Test: `test/test_dechunk/test_main.cpp`
- Modify: `platformio.ini` (ArduinoJson on both envs)

**Interfaces:**
- Produces: `class Dechunker { using ReadFn = int (*)(void*); Dechunker(ReadFn, void* ctx); int read(); size_t readBytes(char*, size_t); bool failed() const; };`
- `read()` returns the next body byte or -1; `ReadFn` returns -1 on end or timeout.
- The pair `read`/`readBytes` is exactly what ArduinoJson accepts as a custom
  input, so `deserializeJson(doc, dechunker)` works on both sides.

`spike/heap/src/stage3.cpp` proved this on hardware but as an Arduino `Stream`,
untestable natively. This is the same algorithm with the source behind a
callback. The bug it prevents is silent: fed the raw chunked body, ArduinoJson
reads the chunk-size line `2561` as a valid JSON number and reports success.

- [ ] **Step 1: Add ArduinoJson to both environments** in `platformio.ini`:
in `[env:esp32]` change the `lib_deps` line to

```ini
lib_deps =
  bodmer/TFT_eSPI@2.5.43
  bblanchon/ArduinoJson@7.4.3
```

and add to `[env:native]`

```ini
lib_deps = bblanchon/ArduinoJson@7.4.3
```

- [ ] **Step 2: Write the failing test** at `test/test_dechunk/test_main.cpp`

```cpp
#include <ArduinoJson.h>
#include <string.h>
#include <unity.h>

#include "dechunk.h"

void setUp() {}
void tearDown() {}

namespace {
struct Source {
  const char* p;
  size_t left;
};

int next_byte(void* ctx) {
  Source* s = static_cast<Source*>(ctx);
  if (s->left == 0) return -1;
  s->left--;
  return static_cast<unsigned char>(*s->p++);
}

std::string drain(const char* wire, size_t len, bool* failed = nullptr) {
  Source src{wire, len};
  Dechunker d(next_byte, &src);
  std::string out;
  for (int c = d.read(); c >= 0; c = d.read()) out.push_back(static_cast<char>(c));
  if (failed != nullptr) *failed = d.failed();
  return out;
}
}  // namespace

void test_unwraps_chunks() {
  const char wire[] = "4\r\nabcd\r\n3\r\nefg\r\n0\r\n\r\n";
  TEST_ASSERT_EQUAL_STRING("abcdefg", drain(wire, sizeof wire - 1).c_str());
}

void test_chunk_sizes_are_hexadecimal() {
  const char wire[] = "a\r\n0123456789\r\n0\r\n\r\n";
  TEST_ASSERT_EQUAL_STRING("0123456789", drain(wire, sizeof wire - 1).c_str());
}

void test_accepts_chunk_extensions() {
  const char wire[] = "4;name=value\r\nabcd\r\n0\r\n\r\n";
  TEST_ASSERT_EQUAL_STRING("abcd", drain(wire, sizeof wire - 1).c_str());
}

void test_a_clean_end_is_not_a_failure() {
  bool failed = true;
  const char wire[] = "1\r\nx\r\n0\r\n\r\n";
  drain(wire, sizeof wire - 1, &failed);
  TEST_ASSERT_FALSE(failed);
}

void test_a_truncated_body_is_a_failure() {
  bool failed = false;
  const char wire[] = "8\r\nabc";  // promised 8 bytes, source dies after 3
  TEST_ASSERT_EQUAL_STRING("abc", drain(wire, sizeof wire - 1, &failed).c_str());
  TEST_ASSERT_TRUE(failed);
}

void test_a_malformed_size_line_is_a_failure() {
  bool failed = false;
  const char wire[] = "zz\r\nabcd\r\n0\r\n\r\n";
  TEST_ASSERT_EQUAL_STRING("", drain(wire, sizeof wire - 1, &failed).c_str());
  TEST_ASSERT_TRUE(failed);
}

void test_read_bytes_fills_the_buffer() {
  const char wire[] = "4\r\nabcd\r\n3\r\nefg\r\n0\r\n\r\n";
  Source src{wire, sizeof wire - 1};
  Dechunker d(next_byte, &src);
  char buf[8] = {0};
  TEST_ASSERT_EQUAL_size_t(7, d.readBytes(buf, sizeof buf - 1));
  TEST_ASSERT_EQUAL_STRING("abcdefg", buf);
}

void test_arduinojson_parses_through_it() {
  // The whole point: this is what AT's GTFS API puts on the wire.
  const char wire[] = "12\r\n{\"data\":[{\"a\":1}\r\n2\r\n]}\r\n0\r\n\r\n";
  Source src{wire, sizeof wire - 1};
  Dechunker d(next_byte, &src);
  JsonDocument doc;
  TEST_ASSERT_FALSE(deserializeJson(doc, d));
  TEST_ASSERT_EQUAL_INT(1, doc["data"][0]["a"].as<int>());
}

void test_without_dechunking_the_same_bytes_parse_as_a_number() {
  // Documents the silent failure this class exists to prevent: the chunk
  // size line is itself valid JSON.
  const char wire[] = "12\r\n{\"data\":[{\"a\":1}\r\n2\r\n]}\r\n0\r\n\r\n";
  JsonDocument doc;
  TEST_ASSERT_FALSE(deserializeJson(doc, wire));
  TEST_ASSERT_TRUE(doc.is<int>());
  TEST_ASSERT_TRUE(doc["data"].isNull());
}

int main(int, char**) {
  UNITY_BEGIN();
  RUN_TEST(test_unwraps_chunks);
  RUN_TEST(test_chunk_sizes_are_hexadecimal);
  RUN_TEST(test_accepts_chunk_extensions);
  RUN_TEST(test_a_clean_end_is_not_a_failure);
  RUN_TEST(test_a_truncated_body_is_a_failure);
  RUN_TEST(test_a_malformed_size_line_is_a_failure);
  RUN_TEST(test_read_bytes_fills_the_buffer);
  RUN_TEST(test_arduinojson_parses_through_it);
  RUN_TEST(test_without_dechunking_the_same_bytes_parse_as_a_number);
  return UNITY_END();
}
```

- [ ] **Step 3: Run it to see it fail**

Run: `pio test -e native -f test_dechunk`
Expected: build error, `dechunk.h: No such file or directory`.

- [ ] **Step 4: Create `lib/core/src/dechunk.h`**

```cpp
#pragma once
#include <stddef.h>
#include <stdint.h>

// Unwraps HTTP chunked transfer-encoding, one chunk header at a time, so
// memory stays flat however large the body is.
//
// AT's GTFS API is chunked. Handing the raw body to a JSON parser is a silent
// failure: it reads the chunk-size line ("2561\r\n") as a valid JSON number,
// stops, and reports success with an empty document - zero departures, no
// error, forever (docs/hardware-notes.md).
//
// read()/readBytes() are the pair ArduinoJson accepts as a custom input, so a
// Dechunker can be passed straight to deserializeJson.
class Dechunker {
 public:
  // Returns the next byte from the transport, or -1 on end-of-stream, error
  // or timeout.
  using ReadFn = int (*)(void* ctx);

  Dechunker(ReadFn fn, void* ctx) : fn_(fn), ctx_(ctx) {}

  int read();
  size_t readBytes(char* buffer, size_t length);

  // True when the framing ended badly: a truncated chunk or an unparsable
  // size line, as opposed to a clean terminating 0-chunk.
  bool failed() const { return failed_; }

 private:
  bool ensure();  // make left_ > 0, reading a chunk header if needed

  ReadFn fn_;
  void* ctx_;
  size_t left_ = 0;
  bool done_ = false;
  bool failed_ = false;
};
```

- [ ] **Step 5: Create `lib/core/src/dechunk.cpp`**

```cpp
#include "dechunk.h"

#include <stdlib.h>
#include <string.h>

int Dechunker::read() {
  if (!ensure()) return -1;
  const int c = fn_(ctx_);
  if (c < 0) {
    done_ = true;
    failed_ = true;  // the chunk promised more than the transport delivered
    return -1;
  }
  if (--left_ == 0) {
    fn_(ctx_);  // \r
    fn_(ctx_);  // \n
  }
  return c;
}

size_t Dechunker::readBytes(char* buffer, size_t length) {
  size_t n = 0;
  while (n < length) {
    const int c = read();
    if (c < 0) break;
    buffer[n++] = static_cast<char>(c);
  }
  return n;
}

bool Dechunker::ensure() {
  if (done_) return false;
  if (left_ > 0) return true;

  char line[24];
  size_t n = 0;
  for (;;) {
    const int c = fn_(ctx_);
    if (c < 0) {
      done_ = true;
      failed_ = true;
      return false;
    }
    if (c == '\n') break;
    if (c != '\r' && n < sizeof line - 1) line[n++] = static_cast<char>(c);
  }
  line[n] = '\0';
  if (n == 0) return ensure();  // stray blank line between chunks

  char* end = nullptr;
  const long size = strtol(line, &end, 16);  // chunk sizes are hex; ";ext" stops it
  if (end == line || size < 0) {
    done_ = true;
    failed_ = true;
    return false;
  }
  if (size == 0) {
    done_ = true;  // clean end
    return false;
  }
  left_ = static_cast<size_t>(size);
  return true;
}
```

- [ ] **Step 6: Run it to see it pass**

Run: `pio test -e native -f test_dechunk`
Expected: `9 test cases: 9 succeeded`.
Run: `pio run -e esp32`
Expected: [SUCCESS] (ArduinoJson now builds into the firmware too).

- [ ] **Step 7: Commit**

```bash
git add platformio.ini lib/core/src/dechunk.h lib/core/src/dechunk.cpp test/test_dechunk/test_main.cpp
git commit -m "Port the de-chunker to pure code, with the silent failure as a test

The spike proved the algorithm on hardware but as an Arduino Stream, which
cannot be tested natively. Behind a read callback it is testable, and one test
pins the bug it exists to prevent: the same bytes fed straight to ArduinoJson
parse as the number 4657 and report success."
```

---

### Task 4: AT URLs, filters and parsers

**Files:**
- Create: `lib/core/src/at_api.h`, `lib/core/src/at_api.cpp`
- Test: `test/test_at_api/test_main.cpp`

**Interfaces:**
- Produces sizes: `TRIP_ID_LEN 48`, `STOP_ID_LEN 24`, `ROUTE_ID_LEN 16`, `SHORT_NAME_LEN 12`, `STOP_CODE_LEN 12`
- Produces structs: `StopInfo`, `RouteInfo`, `StopTripRow`, `TripStop`, `RtEntity` (fields below)
- Produces URL builders returning `false` when truncated:
  `url_stop_by_code`, `url_routes_by_short_name`, `url_rail_routes`, `url_stoptrips`, `url_trip_stops`, `url_realtime`
- Produces filter builders: `stop_filter`, `routes_filter`, `stoptrips_filter`, `trip_stops_filter`, `realtime_filter`
- Produces parsers: `parse_stop`, `parse_routes`, `parse_stoptrips`, `parse_trip_stops`, `parse_realtime`

Every parser runs against a fixture in `test/fixtures/`, parsed **through its
own filter**, so the filters are covered too: a filter that drops a needed
field fails the test rather than the board.

- [ ] **Step 1: Write the failing test** at `test/test_at_api/test_main.cpp`

```cpp
#include <ArduinoJson.h>
#include <stdio.h>
#include <string.h>
#include <unity.h>

#include <string>

#include "at_api.h"

void setUp() {}
void tearDown() {}

namespace {
// Native tests run with the project root as the working directory.
std::string fixture(const char* path) {
  FILE* f = fopen(path, "rb");
  if (f == nullptr) return "";
  std::string out;
  char buf[4096];
  size_t n;
  while ((n = fread(buf, 1, sizeof buf, f)) > 0) out.append(buf, n);
  fclose(f);
  return out;
}

void load(const char* path, JsonDocument& doc, const JsonDocument& filter) {
  const std::string text = fixture(path);
  TEST_ASSERT_TRUE_MESSAGE(!text.empty(), "fixture missing - run pio test from the project root");
  const DeserializationError err =
      deserializeJson(doc, text, DeserializationOption::Filter(filter));
  TEST_ASSERT_FALSE_MESSAGE(err, err.c_str());
}
}  // namespace

void test_urls() {
  char u[256];
  TEST_ASSERT_TRUE(url_stop_by_code(u, sizeof u, "8213"));
  TEST_ASSERT_EQUAL_STRING(
      "https://api.at.govt.nz/gtfs/v3/stops?filter%5Bstop_code%5D=8213", u);

  TEST_ASSERT_TRUE(url_routes_by_short_name(u, sizeof u, "20"));
  TEST_ASSERT_EQUAL_STRING(
      "https://api.at.govt.nz/gtfs/v3/routes?filter%5Broute_short_name%5D=20", u);

  TEST_ASSERT_TRUE(url_rail_routes(u, sizeof u));
  TEST_ASSERT_EQUAL_STRING(
      "https://api.at.govt.nz/gtfs/v3/routes?filter%5Broute_type%5D=2", u);

  TEST_ASSERT_TRUE(url_stoptrips(u, sizeof u, "122-34ecc043", {2026, 9, 19}, 17, 3));
  TEST_ASSERT_EQUAL_STRING(
      "https://api.at.govt.nz/gtfs/v3/stops/122-34ecc043/stoptrips"
      "?filter%5Bdate%5D=2026-09-19&filter%5Bstart_hour%5D=17&filter%5Bhour_range%5D=3", u);

  TEST_ASSERT_TRUE(url_trip_stops(u, sizeof u, "20-02005-54000-2-89a317b8"));
  TEST_ASSERT_EQUAL_STRING(
      "https://api.at.govt.nz/gtfs/v3/trips/20-02005-54000-2-89a317b8/stops", u);

  const char* ids[] = {"a-1", "b-2"};
  TEST_ASSERT_TRUE(url_realtime(u, sizeof u, ids, 2));
  TEST_ASSERT_EQUAL_STRING(
      "https://api.at.govt.nz/realtime/legacy/tripupdates?tripid=a-1,b-2", u);

  char small[32];
  TEST_ASSERT_FALSE(url_realtime(small, sizeof small, ids, 2));  // refuses to truncate
}

void test_start_hour_zero_is_rejected() {
  // The API answers 400 for start_hour=0 (verified live 2026-09-19), so the
  // builder refuses it rather than letting the board ask.
  char u[256];
  TEST_ASSERT_FALSE(url_stoptrips(u, sizeof u, "122-34ecc043", {2026, 9, 19}, 0, 3));
  TEST_ASSERT_FALSE(url_stoptrips(u, sizeof u, "122-34ecc043", {2026, 9, 19}, 24, 3));
}

void test_parse_stop() {
  JsonDocument filter, doc;
  stop_filter(filter);
  load("test/fixtures/post-crl/stops_8213.json", doc, filter);
  StopInfo s{};
  TEST_ASSERT_TRUE(parse_stop(doc, &s));
  TEST_ASSERT_EQUAL_STRING("8213-7e021a72", s.stop_id);
  TEST_ASSERT_EQUAL_INT(0, s.location_type);

  JsonDocument doc2;
  load("test/fixtures/post-crl/stops_122.json", doc2, filter);
  TEST_ASSERT_TRUE(parse_stop(doc2, &s));
  TEST_ASSERT_EQUAL_STRING("122-34ecc043", s.stop_id);
  TEST_ASSERT_EQUAL_INT(1, s.location_type);  // a station
}

void test_an_unknown_stop_code_returns_an_empty_list_not_an_error() {
  JsonDocument filter, doc;
  stop_filter(filter);
  load("test/fixtures/post-crl/stops_unknown.json", doc, filter);
  StopInfo s{};
  TEST_ASSERT_FALSE(parse_stop(doc, &s));
}

void test_parse_routes() {
  JsonDocument filter, doc;
  routes_filter(filter);
  load("test/fixtures/routes_20.json", doc, filter);
  RouteInfo r[8];
  TEST_ASSERT_EQUAL_INT(1, parse_routes(doc, r, 8));
  TEST_ASSERT_EQUAL_STRING("20-202", r[0].route_id);
  TEST_ASSERT_EQUAL_STRING("20", r[0].short_name);
  TEST_ASSERT_EQUAL_INT(3, r[0].route_type);
  TEST_ASSERT_FALSE(r[0].has_color);  // AT omits route_color for buses

  JsonDocument doc2;
  load("test/fixtures/post-crl/routes_rail.json", doc2, filter);
  TEST_ASSERT_EQUAL_INT(8, parse_routes(doc2, r, 8));
  bool saw_ew = false, saw_huia = false;
  for (int i = 0; i < 8; i++) {
    if (strcmp(r[i].route_id, "E-W-201") == 0) {
      saw_ew = true;
      TEST_ASSERT_EQUAL_INT(2, r[i].route_type);
      TEST_ASSERT_TRUE(r[i].has_color);
      TEST_ASSERT_EQUAL_UINT8(0x97, r[i].color.r);
      TEST_ASSERT_EQUAL_UINT8(0xC9, r[i].color.g);
      TEST_ASSERT_EQUAL_UINT8(0x3D, r[i].color.b);
    }
    if (strcmp(r[i].route_id, "HUIA-404") == 0) {
      saw_huia = true;
      TEST_ASSERT_FALSE(r[i].has_color);  // #000000 is unusable on our ground
    }
  }
  TEST_ASSERT_TRUE(saw_ew);
  TEST_ASSERT_TRUE(saw_huia);
}

void test_parse_stoptrips() {
  JsonDocument filter, doc;
  stoptrips_filter(filter);
  load("test/fixtures/post-crl/stoptrips_kingsland.json", doc, filter);
  StopTripRow rows[48];
  const int n = parse_stoptrips(doc, rows, 48);
  TEST_ASSERT_EQUAL_INT(23, n);

  int dir0 = 0, dir1 = 0;
  for (int i = 0; i < n; i++) dir0 += rows[i].direction_id == 0, dir1 += rows[i].direction_id == 1;
  TEST_ASSERT_EQUAL_INT(12, dir0);
  TEST_ASSERT_EQUAL_INT(11, dir1);

  // First row, checked field by field: a station's rows carry the platform id.
  TEST_ASSERT_EQUAL_STRING("258-880001-51480-2-W118540-4f47826a", rows[0].trip_id);
  TEST_ASSERT_EQUAL_STRING("E-W-201", rows[0].route_id);
  TEST_ASSERT_EQUAL_STRING("9305-ef07ca76", rows[0].stop_id);
  TEST_ASSERT_EQUAL_INT(0, rows[0].direction_id);
  TEST_ASSERT_EQUAL_INT32(15 * 3600 + 11 * 60, rows[0].departure_s);
  TEST_ASSERT_EQUAL_INT(2026, rows[0].service_date.y);
  TEST_ASSERT_EQUAL_INT(9, rows[0].service_date.m);
  TEST_ASSERT_EQUAL_INT(13, rows[0].service_date.d);
}

void test_parse_stoptrips_respects_the_cap() {
  JsonDocument filter, doc;
  stoptrips_filter(filter);
  load("test/fixtures/post-crl/stoptrips_8213.json", doc, filter);
  StopTripRow rows[4];
  TEST_ASSERT_EQUAL_INT(4, parse_stoptrips(doc, rows, 4));
}

void test_parse_trip_stops_keeps_sequence_order() {
  JsonDocument filter, doc;
  trip_stops_filter(filter);
  load("test/fixtures/post-crl/trip_dir1_stops.json", doc, filter);
  TripStop stops[40];
  const int n = parse_trip_stops(doc, stops, 40);
  TEST_ASSERT_EQUAL_INT(27, n);
  TEST_ASSERT_EQUAL_STRING("9328", stops[0].stop_code);       // Swanson, first
  TEST_ASSERT_EQUAL_STRING("9304-dcb2ed75", stops[12].stop_id);  // Kingsland platform
  TEST_ASSERT_EQUAL_STRING("9001", stops[16].stop_code);      // Waitemata platform 1
  TEST_ASSERT_EQUAL_STRING("133-08da14b5", stops[16].parent_station);
}

void test_parse_realtime() {
  JsonDocument filter, doc;
  realtime_filter(filter);
  load("test/fixtures/realtime_tripupdates_only.json", doc, filter);
  RtEntity ents[16];
  const int n = parse_realtime(doc, ents, 16);
  TEST_ASSERT_EQUAL_INT(6, n);

  TEST_ASSERT_EQUAL_STRING("20-02005-61200-2-89a317b8", ents[0].trip_id);
  TEST_ASSERT_TRUE(ents[0].has_delay);
  TEST_ASSERT_EQUAL_INT32(-427, ents[0].delay);  // seven minutes early, observed
  TEST_ASSERT_FALSE(ents[0].cancelled);
  TEST_ASSERT_TRUE(ents[0].has_stu_departure);
  TEST_ASSERT_EQUAL_STRING("1060-00b64ee7", ents[0].stu_stop_id);
  TEST_ASSERT_EQUAL_INT32(-427, ents[0].stu_departure_delay);

  // This one's stop_time_update IS our Kingsland platform, and disagrees with
  // the trip-level delay: +66 against -28.
  TEST_ASSERT_EQUAL_STRING("247-810023-61200-2-9731921-77638b11", ents[4].trip_id);
  TEST_ASSERT_EQUAL_INT32(-28, ents[4].delay);
  TEST_ASSERT_EQUAL_STRING("9304-dcb2ed75", ents[4].stu_stop_id);
  TEST_ASSERT_EQUAL_INT32(66, ents[4].stu_departure_delay);

  // And this one has a stop_time_update with no departure at all.
  TEST_ASSERT_EQUAL_STRING("247-810007-60000-2-9729960-592012e4", ents[3].trip_id);
  TEST_ASSERT_FALSE(ents[3].has_stu_departure);
  TEST_ASSERT_EQUAL_INT32(-25, ents[3].delay);
}

int main(int, char**) {
  UNITY_BEGIN();
  RUN_TEST(test_urls);
  RUN_TEST(test_start_hour_zero_is_rejected);
  RUN_TEST(test_parse_stop);
  RUN_TEST(test_an_unknown_stop_code_returns_an_empty_list_not_an_error);
  RUN_TEST(test_parse_routes);
  RUN_TEST(test_parse_stoptrips);
  RUN_TEST(test_parse_stoptrips_respects_the_cap);
  RUN_TEST(test_parse_trip_stops_keeps_sequence_order);
  RUN_TEST(test_parse_realtime);
  return UNITY_END();
}
```

- [ ] **Step 2: Run it to see it fail**

Run: `pio test -e native -f test_at_api`
Expected: build error, `at_api.h: No such file or directory`.

- [ ] **Step 3: Create `lib/core/src/at_api.h`**

```cpp
#pragma once
#include <ArduinoJson.h>
#include <stddef.h>
#include <stdint.h>

#include "color.h"
#include "nztime.h"

// URLs, response filters and parsers for the two AT APIs. Pure: no networking
// here, so every shape below is covered by a fixture in test/fixtures/.
// docs/at-api-notes.md records why each of these looks the way it does.

constexpr int TRIP_ID_LEN = 48;
constexpr int STOP_ID_LEN = 24;
constexpr int ROUTE_ID_LEN = 16;
constexpr int SHORT_NAME_LEN = 12;
constexpr int STOP_CODE_LEN = 12;

struct StopInfo {
  char stop_id[STOP_ID_LEN];
  int location_type;  // 0 stop, 1 station
};

struct RouteInfo {
  char route_id[ROUTE_ID_LEN];
  char short_name[SHORT_NAME_LEN];
  int route_type;  // 2 rail, 3 bus
  bool has_color;
  Rgb color;
};

struct StopTripRow {
  char trip_id[TRIP_ID_LEN];
  char route_id[ROUTE_ID_LEN];
  char stop_id[STOP_ID_LEN];  // the platform for a station's rows
  int8_t direction_id;
  CivilDate service_date;
  int32_t departure_s;  // seconds from the service day's noon minus 12h
};

struct TripStop {
  char stop_id[STOP_ID_LEN];
  char stop_code[STOP_CODE_LEN];
  char parent_station[STOP_ID_LEN];  // "" for stops with no parent
};

struct RtEntity {
  char trip_id[TRIP_ID_LEN];
  bool has_delay;
  int32_t delay;  // trip level, signed; negative is early
  bool cancelled;
  bool has_stu_departure;
  char stu_stop_id[STOP_ID_LEN];
  int32_t stu_departure_delay;
};

// All builders return false rather than emit a truncated URL.
bool url_stop_by_code(char* out, size_t n, const char* stop_code);
bool url_routes_by_short_name(char* out, size_t n, const char* short_name);
bool url_rail_routes(char* out, size_t n);
// start_hour must be 1..23: the API answers 400 for 0 (verified 2026-09-19).
bool url_stoptrips(char* out, size_t n, const char* stop_id, CivilDate date,
                   int start_hour, int hour_range);
bool url_trip_stops(char* out, size_t n, const char* trip_id);
bool url_realtime(char* out, size_t n, const char* const trip_ids[], int count);

void stop_filter(JsonDocument& f);
void routes_filter(JsonDocument& f);
void stoptrips_filter(JsonDocument& f);
void trip_stops_filter(JsonDocument& f);
void realtime_filter(JsonDocument& f);

bool parse_stop(const JsonDocument& doc, StopInfo* out);  // false when data is empty
int parse_routes(const JsonDocument& doc, RouteInfo out[], int cap);
int parse_stoptrips(const JsonDocument& doc, StopTripRow out[], int cap);
int parse_trip_stops(const JsonDocument& doc, TripStop out[], int cap);
int parse_realtime(const JsonDocument& doc, RtEntity out[], int cap);
```

- [ ] **Step 4: Create `lib/core/src/at_api.cpp`**

```cpp
#include "at_api.h"

#include <stdio.h>
#include <string.h>

namespace {

constexpr const char* GTFS = "https://api.at.govt.nz/gtfs/v3";
constexpr const char* REALTIME = "https://api.at.govt.nz/realtime/legacy";

bool put(char* out, size_t n, const char* fmt, ...) __attribute__((format(printf, 3, 4)));

bool put(char* out, size_t n, const char* fmt, ...) {
  va_list args;
  va_start(args, fmt);
  const int written = vsnprintf(out, n, fmt, args);
  va_end(args);
  return written > 0 && static_cast<size_t>(written) < n;
}

void copy(char* dst, size_t size, const char* src) {
  if (src == nullptr) src = "";
  strncpy(dst, src, size - 1);
  dst[size - 1] = '\0';
}

}  // namespace

bool url_stop_by_code(char* out, size_t n, const char* stop_code) {
  return put(out, n, "%s/stops?filter%%5Bstop_code%%5D=%s", GTFS, stop_code);
}

bool url_routes_by_short_name(char* out, size_t n, const char* short_name) {
  return put(out, n, "%s/routes?filter%%5Broute_short_name%%5D=%s", GTFS, short_name);
}

bool url_rail_routes(char* out, size_t n) {
  return put(out, n, "%s/routes?filter%%5Broute_type%%5D=2", GTFS);
}

bool url_stoptrips(char* out, size_t n, const char* stop_id, CivilDate date,
                   int start_hour, int hour_range) {
  if (start_hour < 1 || start_hour > 23 || hour_range < 1) return false;
  char day[16];
  format_iso_date(date, day, sizeof day);
  return put(out, n,
             "%s/stops/%s/stoptrips?filter%%5Bdate%%5D=%s"
             "&filter%%5Bstart_hour%%5D=%d&filter%%5Bhour_range%%5D=%d",
             GTFS, stop_id, day, start_hour, hour_range);
}

bool url_trip_stops(char* out, size_t n, const char* trip_id) {
  return put(out, n, "%s/trips/%s/stops", GTFS, trip_id);
}

bool url_realtime(char* out, size_t n, const char* const trip_ids[], int count) {
  if (count <= 0) return false;
  int written = snprintf(out, n, "%s/tripupdates?tripid=", REALTIME);
  if (written <= 0 || static_cast<size_t>(written) >= n) return false;
  size_t used = static_cast<size_t>(written);
  for (int i = 0; i < count; i++) {
    const int more = snprintf(out + used, n - used, "%s%s", i == 0 ? "" : ",", trip_ids[i]);
    if (more <= 0 || used + static_cast<size_t>(more) >= n) return false;
    used += static_cast<size_t>(more);
  }
  return true;
}

void stop_filter(JsonDocument& f) {
  JsonObject a = f["data"][0]["attributes"].to<JsonObject>();
  a["stop_id"] = true;
  a["location_type"] = true;
}

void routes_filter(JsonDocument& f) {
  JsonObject a = f["data"][0]["attributes"].to<JsonObject>();
  a["route_id"] = true;
  a["route_short_name"] = true;
  a["route_type"] = true;
  a["route_color"] = true;
}

void stoptrips_filter(JsonDocument& f) {
  JsonObject a = f["data"][0]["attributes"].to<JsonObject>();
  a["trip_id"] = true;
  a["route_id"] = true;
  a["stop_id"] = true;
  a["direction_id"] = true;
  a["departure_time"] = true;
  a["service_date"] = true;
}

void trip_stops_filter(JsonDocument& f) {
  JsonObject a = f["data"][0]["attributes"].to<JsonObject>();
  a["stop_id"] = true;
  a["stop_code"] = true;
  a["parent_station"] = true;
}

void realtime_filter(JsonDocument& f) {
  JsonObject e = f["response"]["entity"][0].to<JsonObject>();
  JsonObject tu = e["trip_update"].to<JsonObject>();
  tu["trip"]["trip_id"] = true;
  tu["trip"]["schedule_relationship"] = true;
  tu["delay"] = true;
  // Kept whole: the API sends a single object where the docs promise an array,
  // so a shaped filter would drop one of the two forms.
  tu["stop_time_update"] = true;
}

bool parse_stop(const JsonDocument& doc, StopInfo* out) {
  JsonArrayConst rows = doc["data"].as<JsonArrayConst>();
  if (rows.isNull() || rows.size() == 0) return false;
  JsonObjectConst a = rows[0]["attributes"];
  copy(out->stop_id, sizeof out->stop_id, a["stop_id"] | "");
  out->location_type = a["location_type"] | 0;
  return out->stop_id[0] != '\0';
}

int parse_routes(const JsonDocument& doc, RouteInfo out[], int cap) {
  int n = 0;
  for (JsonObjectConst row : doc["data"].as<JsonArrayConst>()) {
    if (n >= cap) break;
    JsonObjectConst a = row["attributes"];
    RouteInfo& r = out[n];
    copy(r.route_id, sizeof r.route_id, a["route_id"] | "");
    copy(r.short_name, sizeof r.short_name, a["route_short_name"] | "");
    r.route_type = a["route_type"] | 0;
    r.has_color = parse_hex(a["route_color"] | static_cast<const char*>(nullptr), &r.color);
    if (r.route_id[0] != '\0') n++;
  }
  return n;
}

int parse_stoptrips(const JsonDocument& doc, StopTripRow out[], int cap) {
  int n = 0;
  for (JsonObjectConst row : doc["data"].as<JsonArrayConst>()) {
    if (n >= cap) break;
    JsonObjectConst a = row["attributes"];
    StopTripRow& r = out[n];
    copy(r.trip_id, sizeof r.trip_id, a["trip_id"] | "");
    copy(r.route_id, sizeof r.route_id, a["route_id"] | "");
    copy(r.stop_id, sizeof r.stop_id, a["stop_id"] | "");
    r.direction_id = static_cast<int8_t>(a["direction_id"] | -1);
    if (!parse_gtfs_time(a["departure_time"] | "", &r.departure_s)) continue;
    if (!parse_iso_date(a["service_date"] | "", &r.service_date)) continue;
    if (r.trip_id[0] != '\0') n++;
  }
  return n;
}

int parse_trip_stops(const JsonDocument& doc, TripStop out[], int cap) {
  int n = 0;
  // Order is positional - these rows carry no stop_sequence, so never sort them.
  for (JsonObjectConst row : doc["data"].as<JsonArrayConst>()) {
    if (n >= cap) break;
    JsonObjectConst a = row["attributes"];
    TripStop& s = out[n];
    copy(s.stop_id, sizeof s.stop_id, a["stop_id"] | "");
    copy(s.stop_code, sizeof s.stop_code, a["stop_code"] | "");
    copy(s.parent_station, sizeof s.parent_station, a["parent_station"] | "");
    if (s.stop_id[0] != '\0') n++;
  }
  return n;
}

int parse_realtime(const JsonDocument& doc, RtEntity out[], int cap) {
  int n = 0;
  for (JsonObjectConst ent : doc["response"]["entity"].as<JsonArrayConst>()) {
    if (n >= cap) break;
    JsonObjectConst tu = ent["trip_update"];
    if (tu.isNull()) continue;
    RtEntity& e = out[n];
    memset(&e, 0, sizeof e);
    copy(e.trip_id, sizeof e.trip_id, tu["trip"]["trip_id"] | "");
    e.has_delay = !tu["delay"].isNull();
    e.delay = tu["delay"] | 0;
    e.cancelled = (tu["trip"]["schedule_relationship"] | 0) == 3;

    // The docs promise an array; the API sends one object. Accept both, taking
    // the first element of an array.
    JsonVariantConst stu = tu["stop_time_update"];
    if (stu.is<JsonArrayConst>()) stu = stu[0];
    if (!stu.isNull()) {
      copy(e.stu_stop_id, sizeof e.stu_stop_id, stu["stop_id"] | "");
      JsonVariantConst dep = stu["departure"];
      if (!dep.isNull() && !dep["delay"].isNull()) {
        e.has_stu_departure = true;
        e.stu_departure_delay = dep["delay"] | 0;
      }
    }
    if (e.trip_id[0] != '\0') n++;
  }
  return n;
}
```

Add `#include <stdarg.h>` at the top of the file if the compiler asks for it.

- [ ] **Step 5: Run it to see it pass**

Run: `pio test -e native -f test_at_api`
Expected: `9 test cases: 9 succeeded`.

- [ ] **Step 6: Commit**

```bash
git add lib/core/src/at_api.h lib/core/src/at_api.cpp test/test_at_api/test_main.cpp
git commit -m "Parse the AT APIs against the captured fixtures

Every parser is exercised through its own ArduinoJson filter, so a filter that
drops a field the board needs fails a test instead of the board. The awkward
shapes from docs/at-api-notes.md are pinned: a stop_time_update that is an
object rather than an array, a bus route with no colour, HUIA's #000000, and
start_hour=0 which the API rejects outright."
```

---

### Task 5: The live merge — direction, selection, board

**Files:**
- Create: `lib/core/src/live.h`, `lib/core/src/live.cpp`
- Test: `test/test_live/test_main.cpp`

**Interfaces:**
- Produces: `struct WatchConfig { const char* label; const char* stop_code; const char* route_short_name; const char* toward_stop_code; };`
- Produces: `enum class WatchState : uint8_t { Starting, Ok, CheckConfig, CheckKey, StopLookupGone };`
- Produces: `struct LiveRow`, `struct LiveWatch`, `struct Snapshot` (below)
- Produces: `const char* state_message(WatchState)`
- Produces: `bool trip_serves(const TripStop[], int, const char* our_stop_id, const char* target_code, const char* target_stop_id)`
- Produces: `int choose_direction(const bool present[2], const bool serves[2])` → 0, 1, `DIR_NONE`, `DIR_UNPROVABLE`
- Produces: `int select_rows(const StopTripRow[], int, int direction, const char* const route_ids[], int n_routes, int64_t now, LiveRow out[], int cap)`
- Produces: `void apply_realtime(LiveWatch&, const RtEntity[], int)`
- Produces: `int realtime_ids(const Snapshot&, int64_t now, const char* out[], int cap, int per_watch)`
- Produces: `struct FetchWindow { CivilDate date; int start_hour; int hour_range; };`
  and `int schedule_windows(const LocalTime& now, FetchWindow out[2]);`
- Produces: `Board build_board(const Snapshot&, const WatchConfig[], const char* location, int64_t now, uint8_t theme)`

- [ ] **Step 1: Write the failing test** at `test/test_live/test_main.cpp`

```cpp
#include <string.h>
#include <unity.h>

#include "live.h"

void setUp() {}
void tearDown() {}

namespace {
// Kingsland, 2026-09-13, from the post-CRL fixtures.
constexpr int64_t T_15_00 = 1789268400;  // 2026-09-13 15:00:00 NZST

TripStop stop(const char* id, const char* code, const char* parent) {
  TripStop s{};
  strncpy(s.stop_id, id, sizeof s.stop_id - 1);
  strncpy(s.stop_code, code, sizeof s.stop_code - 1);
  strncpy(s.parent_station, parent, sizeof s.parent_station - 1);
  return s;
}

StopTripRow row(const char* trip, const char* route, int dir, int32_t secs) {
  StopTripRow r{};
  strncpy(r.trip_id, trip, sizeof r.trip_id - 1);
  strncpy(r.route_id, route, sizeof r.route_id - 1);
  strncpy(r.stop_id, "9305-ef07ca76", sizeof r.stop_id - 1);
  r.direction_id = static_cast<int8_t>(dir);
  r.service_date = {2026, 9, 13};
  r.departure_s = secs;
  return r;
}
}  // namespace

void test_a_trip_serves_a_target_that_comes_after_us() {
  // The real dir-1 trip: Kingsland platform 9304 at index 12, Waitemata
  // platform 9001 (parent 133) at 16.
  const TripStop stops[] = {
      stop("9328-f6f84eac", "9328", "127-2affe079"),
      stop("9304-dcb2ed75", "9304", "122-34ecc043"),
      stop("9001-11111111", "9001", "133-08da14b5"),
  };
  TEST_ASSERT_TRUE(trip_serves(stops, 3, "9304-dcb2ed75", "133", "133-08da14b5"));
}

void test_a_trip_going_the_other_way_does_not_serve_it() {
  // The real dir-0 trip passes Waitemata BEFORE Kingsland, so it is no use.
  const TripStop stops[] = {
      stop("9004-22222222", "9004", "133-08da14b5"),
      stop("9305-ef07ca76", "9305", "122-34ecc043"),
      stop("9328-f6f84eac", "9328", "127-2affe079"),
  };
  TEST_ASSERT_FALSE(trip_serves(stops, 3, "9305-ef07ca76", "133", "133-08da14b5"));
}

void test_a_bus_target_matches_on_stop_code_alone() {
  const TripStop stops[] = {
      stop("8213-7e021a72", "8213", ""),
      stop("1060-00b64ee7", "1060", ""),
  };
  TEST_ASSERT_TRUE(trip_serves(stops, 2, "8213-7e021a72", "1060", "1060-00b64ee7"));
}

void test_a_trip_that_never_calls_at_our_stop_serves_nothing() {
  const TripStop stops[] = {stop("1111-aaaa", "1111", ""), stop("1060-00b64ee7", "1060", "")};
  TEST_ASSERT_FALSE(trip_serves(stops, 2, "8213-7e021a72", "1060", "1060-00b64ee7"));
}

void test_choose_direction() {
  const bool both[2] = {true, true};
  const bool one_serves[2] = {false, true};
  TEST_ASSERT_EQUAL_INT(1, choose_direction(both, one_serves));

  const bool zero_serves[2] = {true, false};
  TEST_ASSERT_EQUAL_INT(0, choose_direction(both, zero_serves));

  // Both ways run and neither reaches the target: the config is wrong.
  const bool neither[2] = {false, false};
  TEST_ASSERT_EQUAL_INT(DIR_UNPROVABLE, choose_direction(both, neither));

  // Only one direction is running and it does not go our way: nothing is due,
  // which is an empty board, not a misconfiguration.
  const bool only_zero[2] = {true, false};
  TEST_ASSERT_EQUAL_INT(DIR_NONE, choose_direction(only_zero, neither));
}

void test_select_rows_filters_by_direction_and_route() {
  const StopTripRow rows[] = {
      row("a", "E-W-201", 0, 15 * 3600 + 11 * 60),
      row("b", "E-W-201", 1, 15 * 3600 + 13 * 60),
      row("c", "O-W-201", 1, 15 * 3600 + 20 * 60),
      row("d", "E-W-201", 1, 15 * 3600 + 30 * 60),
  };
  LiveRow out[8];
  TEST_ASSERT_EQUAL_INT(3, select_rows(rows, 4, 1, nullptr, 0, T_15_00, out, 8));
  TEST_ASSERT_EQUAL_STRING("b", out[0].trip_id);

  const char* only_ew[] = {"E-W-201"};
  TEST_ASSERT_EQUAL_INT(2, select_rows(rows, 4, 1, only_ew, 1, T_15_00, out, 8));
  TEST_ASSERT_EQUAL_STRING("b", out[0].trip_id);
  TEST_ASSERT_EQUAL_STRING("d", out[1].trip_id);
  TEST_ASSERT_EQUAL_INT64(T_15_00 + 13 * 60, out[0].sched_epoch);
}

void test_select_rows_keeps_recent_departures_because_delays_can_be_large() {
  // Scheduled 10 minutes ago, but a bus can run 7 minutes late; dropping it
  // here would lose a service that is still to come.
  const StopTripRow rows[] = {row("a", "E-W-201", 1, 14 * 3600 + 50 * 60),
                              row("b", "E-W-201", 1, 13 * 3600)};
  LiveRow out[4];
  TEST_ASSERT_EQUAL_INT(1, select_rows(rows, 2, 1, nullptr, 0, T_15_00, out, 4));
  TEST_ASSERT_EQUAL_STRING("a", out[0].trip_id);
}

void test_apply_realtime_prefers_our_own_stop_time_update() {
  LiveWatch w{};
  w.n_rows = 2;
  strncpy(w.rows[0].trip_id, "t1", sizeof w.rows[0].trip_id - 1);
  strncpy(w.rows[0].stop_id, "9304-dcb2ed75", sizeof w.rows[0].stop_id - 1);
  strncpy(w.rows[1].trip_id, "t2", sizeof w.rows[1].trip_id - 1);
  strncpy(w.rows[1].stop_id, "9304-dcb2ed75", sizeof w.rows[1].stop_id - 1);

  RtEntity ents[3]{};
  strncpy(ents[0].trip_id, "t1", sizeof ents[0].trip_id - 1);
  ents[0].has_delay = true;
  ents[0].delay = -28;
  ents[0].has_stu_departure = true;
  strncpy(ents[0].stu_stop_id, "9304-dcb2ed75", sizeof ents[0].stu_stop_id - 1);
  ents[0].stu_departure_delay = 66;

  strncpy(ents[1].trip_id, "t2", sizeof ents[1].trip_id - 1);
  ents[1].has_delay = true;
  ents[1].delay = -427;
  ents[1].has_stu_departure = true;
  strncpy(ents[1].stu_stop_id, "1060-00b64ee7", sizeof ents[1].stu_stop_id - 1);
  ents[1].stu_departure_delay = 999;

  // A trip we never asked about: the tripid filter is inexact.
  strncpy(ents[2].trip_id, "stranger", sizeof ents[2].trip_id - 1);
  ents[2].has_delay = true;
  ents[2].delay = 12345;

  apply_realtime(w, ents, 3);
  TEST_ASSERT_TRUE(w.rows[0].has_rt);
  TEST_ASSERT_EQUAL_INT32(66, w.rows[0].delay);     // our stop wins
  TEST_ASSERT_EQUAL_INT32(-427, w.rows[1].delay);   // someone else's is ignored
}

void test_apply_realtime_marks_cancellations() {
  LiveWatch w{};
  w.n_rows = 1;
  strncpy(w.rows[0].trip_id, "t1", sizeof w.rows[0].trip_id - 1);
  RtEntity e{};
  strncpy(e.trip_id, "t1", sizeof e.trip_id - 1);
  e.cancelled = true;
  apply_realtime(w, &e, 1);
  TEST_ASSERT_TRUE(w.rows[0].cancelled);
}

void test_build_board_turns_a_snapshot_into_what_the_screen_draws() {
  const WatchConfig cfg[] = {
      {"to Wynyard Quarter", "8213", "20", "1060"},
      {"to Waitemata", "122", "", "133"},
  };
  Snapshot s{};
  s.n_watches = 2;
  s.last_ok = T_15_00 - 10;
  s.poll_interval_s = 30;

  s.watches[0].state = WatchState::Ok;
  s.watches[0].kind = Kind::Bus;
  strncpy(s.watches[0].badge, "20", sizeof s.watches[0].badge - 1);
  s.watches[0].n_rows = 2;
  s.watches[0].rows[0].sched_epoch = T_15_00 + 240;
  s.watches[0].rows[0].has_rt = true;
  s.watches[0].rows[0].delay = 60;  // a minute late: eta 300
  s.watches[0].rows[1].sched_epoch = T_15_00 + 1020;

  s.watches[1].state = WatchState::CheckConfig;
  s.watches[1].kind = Kind::Train;
  strncpy(s.watches[1].badge, "E-W", sizeof s.watches[1].badge - 1);
  s.watches[1].n_rows = 1;
  s.watches[1].rows[0].sched_epoch = T_15_00 + 420;

  const Board b = build_board(s, cfg, "Kingsland", T_15_00, 0);
  TEST_ASSERT_EQUAL_UINT8(2, b.n_watches);
  TEST_ASSERT_EQUAL_STRING("Kingsland", b.location);
  TEST_ASSERT_EQUAL_STRING("15:00", b.clock);

  TEST_ASSERT_EQUAL_STRING("20", b.watches[0].badge);
  TEST_ASSERT_EQUAL_STRING("to Wynyard Quarter", b.watches[0].headsign);
  TEST_ASSERT_EQUAL_STRING("", b.watches[0].message);
  TEST_ASSERT_EQUAL_UINT8(2, b.watches[0].n_deps);
  TEST_ASSERT_EQUAL_INT32(300, b.watches[0].next()->eta_s);
  TEST_ASSERT_TRUE(b.watches[0].next()->live);
  TEST_ASSERT_EQUAL_INT32(1020, b.watches[0].following()->eta_s);
  TEST_ASSERT_FALSE(b.watches[0].following()->live);

  // A watch that cannot prove its direction shows a message and no times.
  TEST_ASSERT_EQUAL_STRING("check config", b.watches[1].message);
  TEST_ASSERT_EQUAL_UINT8(0, b.watches[1].n_deps);
}

void test_build_board_drops_departures_that_have_left() {
  const WatchConfig cfg[] = {{"to Wynyard Quarter", "8213", "20", "1060"}};
  Snapshot s{};
  s.n_watches = 1;
  s.last_ok = T_15_00;
  s.poll_interval_s = 30;
  s.watches[0].state = WatchState::Ok;
  s.watches[0].n_rows = 2;
  s.watches[0].rows[0].sched_epoch = T_15_00 - 120;  // gone
  s.watches[0].rows[1].sched_epoch = T_15_00 + 300;

  const Board b = build_board(s, cfg, "Kingsland", T_15_00, 0);
  TEST_ASSERT_EQUAL_UINT8(1, b.watches[0].n_deps);
  TEST_ASSERT_EQUAL_INT32(300, b.watches[0].next()->eta_s);
}

void test_build_board_orders_by_the_time_the_service_will_actually_leave() {
  const WatchConfig cfg[] = {{"to Wynyard Quarter", "8213", "20", "1060"}};
  Snapshot s{};
  s.n_watches = 1;
  s.last_ok = T_15_00;
  s.poll_interval_s = 30;
  s.watches[0].state = WatchState::Ok;
  s.watches[0].n_rows = 2;
  s.watches[0].rows[0].sched_epoch = T_15_00 + 120;
  s.watches[0].rows[0].has_rt = true;
  s.watches[0].rows[0].delay = 600;  // ten minutes late, so it is now second
  s.watches[0].rows[1].sched_epoch = T_15_00 + 300;

  const Board b = build_board(s, cfg, "Kingsland", T_15_00, 0);
  TEST_ASSERT_EQUAL_INT32(300, b.watches[0].next()->eta_s);
  TEST_ASSERT_EQUAL_INT32(720, b.watches[0].following()->eta_s);
}

void test_staleness_is_measured_against_the_polling_interval() {
  const WatchConfig cfg[] = {{"to Wynyard Quarter", "8213", "20", "1060"}};
  Snapshot s{};
  s.n_watches = 1;
  s.watches[0].state = WatchState::Ok;
  s.poll_interval_s = 30;

  s.last_ok = T_15_00 - 30;  // a poll due now is not late
  TEST_ASSERT_EQUAL_INT32(0, build_board(s, cfg, "K", T_15_00, 0).stale_s);

  s.last_ok = T_15_00 - 270;  // four minutes overdue
  const Board b = build_board(s, cfg, "K", T_15_00, 0);
  TEST_ASSERT_EQUAL_INT32(240, b.stale_s);
  TEST_ASSERT_TRUE(b.is_stale());

  s.last_ok = 0;  // nothing has ever arrived: Starting says so instead
  TEST_ASSERT_EQUAL_INT32(0, build_board(s, cfg, "K", T_15_00, 0).stale_s);
}

void test_realtime_ids_asks_only_about_services_still_to_come() {
  Snapshot s{};
  s.n_watches = 1;
  s.watches[0].state = WatchState::Ok;
  s.watches[0].n_rows = 3;
  strncpy(s.watches[0].rows[0].trip_id, "gone", sizeof s.watches[0].rows[0].trip_id - 1);
  s.watches[0].rows[0].sched_epoch = T_15_00 - 3600;
  strncpy(s.watches[0].rows[1].trip_id, "soon", sizeof s.watches[0].rows[1].trip_id - 1);
  s.watches[0].rows[1].sched_epoch = T_15_00 + 300;
  strncpy(s.watches[0].rows[2].trip_id, "later", sizeof s.watches[0].rows[2].trip_id - 1);
  s.watches[0].rows[2].sched_epoch = T_15_00 + 900;

  const char* ids[8];
  TEST_ASSERT_EQUAL_INT(2, realtime_ids(s, T_15_00, ids, 8, 6));
  TEST_ASSERT_EQUAL_STRING("soon", ids[0]);
  TEST_ASSERT_EQUAL_STRING("later", ids[1]);

  TEST_ASSERT_EQUAL_INT(1, realtime_ids(s, T_15_00, ids, 8, 1));  // per-watch cap
}

void test_schedule_windows_cover_three_hours_from_now() {
  FetchWindow w[2];
  LocalTime t{};
  t.y = 2026;
  t.m = 9;
  t.d = 19;
  t.hour = 17;
  TEST_ASSERT_EQUAL_INT(1, schedule_windows(t, w));
  TEST_ASSERT_EQUAL_INT(2026, w[0].date.y);
  TEST_ASSERT_EQUAL_INT(19, w[0].date.d);
  TEST_ASSERT_EQUAL_INT(17, w[0].start_hour);
  TEST_ASSERT_EQUAL_INT(3, w[0].hour_range);
}

void test_schedule_windows_split_at_midnight_because_the_api_clamps() {
  FetchWindow w[2];
  LocalTime t{};
  t.y = 2026;
  t.m = 9;
  t.d = 19;
  t.hour = 23;
  TEST_ASSERT_EQUAL_INT(2, schedule_windows(t, w));
  TEST_ASSERT_EQUAL_INT(19, w[0].date.d);
  TEST_ASSERT_EQUAL_INT(23, w[0].start_hour);
  TEST_ASSERT_EQUAL_INT(1, w[0].hour_range);
  TEST_ASSERT_EQUAL_INT(20, w[1].date.d);  // next service date
  TEST_ASSERT_EQUAL_INT(1, w[1].start_hour);  // never 0: the API rejects it
  TEST_ASSERT_EQUAL_INT(2, w[1].hour_range);
}

void test_schedule_windows_never_ask_for_hour_zero() {
  FetchWindow w[2];
  LocalTime t{};
  t.y = 2026;
  t.m = 9;
  t.d = 20;
  t.hour = 0;
  TEST_ASSERT_EQUAL_INT(1, schedule_windows(t, w));
  TEST_ASSERT_EQUAL_INT(20, w[0].date.d);
  TEST_ASSERT_EQUAL_INT(1, w[0].start_hour);
  TEST_ASSERT_EQUAL_INT(3, w[0].hour_range);
}

void test_schedule_windows_roll_over_a_month_end() {
  FetchWindow w[2];
  LocalTime t{};
  t.y = 2026;
  t.m = 9;
  t.d = 30;
  t.hour = 23;
  TEST_ASSERT_EQUAL_INT(2, schedule_windows(t, w));
  TEST_ASSERT_EQUAL_INT(10, w[1].date.m);
  TEST_ASSERT_EQUAL_INT(1, w[1].date.d);
}

void test_state_messages() {
  TEST_ASSERT_EQUAL_STRING("", state_message(WatchState::Ok));
  TEST_ASSERT_EQUAL_STRING("check config", state_message(WatchState::CheckConfig));
  TEST_ASSERT_EQUAL_STRING("check API key", state_message(WatchState::CheckKey));
  TEST_ASSERT_EQUAL_STRING("starting", state_message(WatchState::Starting));
  TEST_ASSERT_EQUAL_STRING("stop lookup gone", state_message(WatchState::StopLookupGone));
}

int main(int, char**) {
  UNITY_BEGIN();
  RUN_TEST(test_a_trip_serves_a_target_that_comes_after_us);
  RUN_TEST(test_a_trip_going_the_other_way_does_not_serve_it);
  RUN_TEST(test_a_bus_target_matches_on_stop_code_alone);
  RUN_TEST(test_a_trip_that_never_calls_at_our_stop_serves_nothing);
  RUN_TEST(test_choose_direction);
  RUN_TEST(test_select_rows_filters_by_direction_and_route);
  RUN_TEST(test_select_rows_keeps_recent_departures_because_delays_can_be_large);
  RUN_TEST(test_apply_realtime_prefers_our_own_stop_time_update);
  RUN_TEST(test_apply_realtime_marks_cancellations);
  RUN_TEST(test_build_board_turns_a_snapshot_into_what_the_screen_draws);
  RUN_TEST(test_build_board_drops_departures_that_have_left);
  RUN_TEST(test_build_board_orders_by_the_time_the_service_will_actually_leave);
  RUN_TEST(test_staleness_is_measured_against_the_polling_interval);
  RUN_TEST(test_realtime_ids_asks_only_about_services_still_to_come);
  RUN_TEST(test_schedule_windows_cover_three_hours_from_now);
  RUN_TEST(test_schedule_windows_split_at_midnight_because_the_api_clamps);
  RUN_TEST(test_schedule_windows_never_ask_for_hour_zero);
  RUN_TEST(test_schedule_windows_roll_over_a_month_end);
  RUN_TEST(test_state_messages);
  return UNITY_END();
}
```

- [ ] **Step 2: Run it to see it fail**

Run: `pio test -e native -f test_live`
Expected: build error, `live.h: No such file or directory`.

- [ ] **Step 3: Create `lib/core/src/live.h`**

```cpp
#pragma once
#include <stdint.h>

#include "at_api.h"
#include "model.h"

// Everything between "the API answered" and "the screen draws". Pure, so the
// rules that decide what the board claims are tested on a laptop.

struct WatchConfig {
  const char* label;             // headsign line, e.g. "to Wynyard Quarter"
  const char* stop_code;         // the number on the pole, e.g. "8213"
  const char* route_short_name;  // "" means any route (spec 3)
  const char* toward_stop_code;  // the stop being travelled toward (spec 3a)
};

enum class WatchState : uint8_t {
  Starting,        // nothing fetched yet
  Ok,
  CheckConfig,     // direction cannot be derived, or the stop code is unknown
  CheckKey,        // 401
  StopLookupGone,  // filter[stop_code] started 400ing (spec 8)
};

const char* state_message(WatchState s);  // "" for Ok

constexpr int MAX_ROWS = 16;      // scheduled departures kept per watch
constexpr int DIR_NONE = -1;      // nothing runs our way in this window
constexpr int DIR_UNPROVABLE = -2;

struct LiveRow {
  char trip_id[TRIP_ID_LEN];
  char stop_id[STOP_ID_LEN];
  int64_t sched_epoch;
  bool has_rt;
  int32_t delay;
  bool cancelled;
};

struct LiveWatch {
  WatchState state;
  Kind kind;
  char badge[8];
  bool has_route_color;
  Rgb route_color;
  LiveRow rows[MAX_ROWS];
  uint8_t n_rows;
};

struct Snapshot {
  LiveWatch watches[MAX_WATCHES];
  uint8_t n_watches;
  int64_t last_ok;         // epoch of the last successful fetch, 0 if never
  int32_t poll_interval_s; // what the fetcher is currently aiming for
};

// Does this trip call at our stop and then reach the target? Platforms carry a
// parent_station, so a station target matches either the code or the parent.
bool trip_serves(const TripStop stops[], int n, const char* our_stop_id,
                 const char* target_code, const char* target_stop_id);

// Which direction_id to believe, given which directions have trips in the
// window and which of them reach the target.
int choose_direction(const bool present[2], const bool serves[2]);

int select_rows(const StopTripRow rows[], int n, int direction,
                const char* const route_ids[], int n_routes, int64_t now,
                LiveRow out[], int cap);

// Applies delays and cancellations to rows whose trip_id we asked for; entities
// for any other trip are discarded (the tripid filter is inexact).
void apply_realtime(LiveWatch& w, const RtEntity ents[], int n);

// Trip ids worth asking realtime about: those still to come, at most
// per_watch from each watch.
int realtime_ids(const Snapshot& s, int64_t now, const char* out[], int cap, int per_watch);

struct FetchWindow {
  CivilDate date;
  int start_hour;  // always 1..23
  int hour_range;
};

// The stoptrips request(s) covering the next three hours. hour_range is clamped
// to the service day by the API, so a window crossing midnight needs a second
// request against the next date - and start_hour is never 0, which the API
// rejects with 400. Returns 1 or 2.
int schedule_windows(const LocalTime& now, FetchWindow out[2]);

Board build_board(const Snapshot& s, const WatchConfig cfg[], const char* location,
                  int64_t now, uint8_t theme);
```

- [ ] **Step 4: Create `lib/core/src/live.cpp`**

```cpp
#include "live.h"

#include <string.h>

namespace {

// A service scheduled this long ago may still be ahead of us: delays of -427 s
// are real, and so are late ones.
constexpr int64_t KEEP_PAST_S = 1800;

struct Candidate {
  int32_t eta_s;
  bool live;
  bool cancelled;
};

void sort_candidates(Candidate c[], int n) {
  for (int i = 1; i < n; i++) {  // insertion sort: stable, n is tiny
    const Candidate v = c[i];
    int j = i - 1;
    while (j >= 0 && c[j].eta_s > v.eta_s) {
      c[j + 1] = c[j];
      j--;
    }
    c[j + 1] = v;
  }
}

}  // namespace

const char* state_message(WatchState s) {
  switch (s) {
    case WatchState::Ok: return "";
    case WatchState::Starting: return "starting";
    case WatchState::CheckConfig: return "check config";
    case WatchState::CheckKey: return "check API key";
    case WatchState::StopLookupGone: return "stop lookup gone";
  }
  return "";
}

bool trip_serves(const TripStop stops[], int n, const char* our_stop_id,
                 const char* target_code, const char* target_stop_id) {
  int ours = -1;
  for (int i = 0; i < n; i++) {
    if (strcmp(stops[i].stop_id, our_stop_id) == 0) {
      ours = i;
      break;
    }
  }
  if (ours < 0) return false;
  for (int i = ours + 1; i < n; i++) {
    if (strcmp(stops[i].stop_code, target_code) == 0) return true;
    if (target_stop_id != nullptr && target_stop_id[0] != '\0' &&
        strcmp(stops[i].parent_station, target_stop_id) == 0) {
      return true;
    }
  }
  return false;
}

int choose_direction(const bool present[2], const bool serves[2]) {
  for (int d = 0; d < 2; d++) {
    if (present[d] && serves[d]) return d;
  }
  // Both directions are running and neither reaches the target: the watch is
  // pointed at a stop this service does not serve.
  if (present[0] && present[1]) return DIR_UNPROVABLE;
  return DIR_NONE;
}

int select_rows(const StopTripRow rows[], int n, int direction,
                const char* const route_ids[], int n_routes, int64_t now,
                LiveRow out[], int cap) {
  int count = 0;
  for (int i = 0; i < n && count < cap; i++) {
    const StopTripRow& r = rows[i];
    if (r.direction_id != direction) continue;
    if (n_routes > 0) {
      bool wanted = false;
      for (int k = 0; k < n_routes; k++) {
        if (strcmp(r.route_id, route_ids[k]) == 0) {
          wanted = true;
          break;
        }
      }
      if (!wanted) continue;
    }
    const int64_t sched = gtfs_epoch(r.service_date, r.departure_s);
    if (sched < now - KEEP_PAST_S) continue;
    LiveRow& o = out[count];
    memset(&o, 0, sizeof o);
    strncpy(o.trip_id, r.trip_id, sizeof o.trip_id - 1);
    strncpy(o.stop_id, r.stop_id, sizeof o.stop_id - 1);
    o.sched_epoch = sched;
    count++;
  }
  for (int i = 1; i < count; i++) {  // by scheduled time, stable
    const LiveRow v = out[i];
    int j = i - 1;
    while (j >= 0 && out[j].sched_epoch > v.sched_epoch) {
      out[j + 1] = out[j];
      j--;
    }
    out[j + 1] = v;
  }
  return count;
}

void apply_realtime(LiveWatch& w, const RtEntity ents[], int n) {
  for (int i = 0; i < w.n_rows; i++) {
    LiveRow& row = w.rows[i];
    for (int e = 0; e < n; e++) {
      const RtEntity& ent = ents[e];
      if (strcmp(ent.trip_id, row.trip_id) != 0) continue;  // re-filter: the
                                                            // tripid query is inexact
      row.cancelled = ent.cancelled;
      // The per-stop update usually describes the vehicle's next stop, not
      // ours; prefer it only when it really is ours.
      if (ent.has_stu_departure && strcmp(ent.stu_stop_id, row.stop_id) == 0) {
        row.delay = ent.stu_departure_delay;
        row.has_rt = true;
      } else if (ent.has_delay) {
        row.delay = ent.delay;
        row.has_rt = true;
      }
      break;
    }
  }
}

int realtime_ids(const Snapshot& s, int64_t now, const char* out[], int cap, int per_watch) {
  int count = 0;
  for (int i = 0; i < s.n_watches && count < cap; i++) {
    const LiveWatch& w = s.watches[i];
    if (w.state != WatchState::Ok) continue;
    int taken = 0;
    for (int r = 0; r < w.n_rows && count < cap && taken < per_watch; r++) {
      const LiveRow& row = w.rows[r];
      if (row.trip_id[0] == '\0') continue;
      if (row.sched_epoch + row.delay < now - 60) continue;
      out[count++] = row.trip_id;
      taken++;
    }
  }
  return count;
}

int schedule_windows(const LocalTime& now, FetchWindow out[2]) {
  constexpr int LOOKAHEAD_H = 3;
  // Hour 0 is rejected by the API, so the first hour we can ask for is 1; a
  // departure between 00:00 and 00:59 is simply not fetchable.
  const int start = now.hour < 1 ? 1 : now.hour;
  const CivilDate today{now.y, now.m, now.d};
  if (start + LOOKAHEAD_H <= 24) {
    out[0] = {today, start, LOOKAHEAD_H};
    return 1;
  }
  out[0] = {today, start, 24 - start};
  out[1] = {civil_from_days(days_from_civil(today.y, today.m, today.d) + 1), 1,
            start + LOOKAHEAD_H - 24};
  return 2;
}

Board build_board(const Snapshot& s, const WatchConfig cfg[], const char* location,
                  int64_t now, uint8_t theme) {
  Board b;
  memset(&b, 0, sizeof b);
  b.n_watches = s.n_watches;
  b.theme = theme;
  board_set_location(&b, location);
  format_clock(now, b.clock, sizeof b.clock);

  // Overdue, not elapsed: at the slow cadence a two-minute gap is normal.
  if (s.last_ok > 0) {
    const int64_t overdue = now - s.last_ok - s.poll_interval_s;
    b.stale_s = overdue > 0 ? static_cast<int32_t>(overdue) : 0;
  }

  for (int i = 0; i < s.n_watches; i++) {
    const LiveWatch& lw = s.watches[i];
    Watch& w = b.watches[i];
    watch_init(&w, lw.badge, cfg[i].label, lw.kind, nullptr);
    w.has_route_color = lw.has_route_color;
    w.route_color = lw.route_color;
    watch_set_message(&w, state_message(lw.state));
    if (lw.state != WatchState::Ok) continue;

    Candidate cand[MAX_ROWS];
    int n = 0;
    for (int r = 0; r < lw.n_rows; r++) {
      const LiveRow& row = lw.rows[r];
      const int64_t eta = row.sched_epoch + (row.has_rt ? row.delay : 0) - now;
      if (eta < 0) continue;  // it has left; the next one is promoted
      cand[n].eta_s = static_cast<int32_t>(eta);
      cand[n].live = row.has_rt;
      cand[n].cancelled = row.cancelled;
      n++;
    }
    sort_candidates(cand, n);
    for (int k = 0; k < n; k++) {
      if (!w.add({cand[k].eta_s, cand[k].live, cand[k].cancelled})) break;
    }
  }
  return b;
}
```

- [ ] **Step 5: Run it to see it pass**

Run: `pio test -e native -f test_live`
Expected: `19 test cases: 19 succeeded`.

- [ ] **Step 6: Commit**

```bash
git add lib/core/src/live.h lib/core/src/live.cpp test/test_live/test_main.cpp
git commit -m "Merge schedule, direction and delays into a Board, on a laptop

The rules that decide what the board claims are the ones worth testing off the
device: which direction actually reaches your destination, which delay to
believe when the per-stop update is about someone else's stop, what to do with
a trip the realtime feed threw in unasked, and when 'stale' is honest rather
than merely overdue by a polling interval."
```

---
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

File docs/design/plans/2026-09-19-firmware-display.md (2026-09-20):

# Firmware Display Implementation Plan

> **For agentic workers:** REQUIRED SUB-SKILL: Use superpowers:subagent-driven-development (recommended) or superpowers:executing-plans to implement this plan task-by-task. Steps use checkbox (`- [ ]`) syntax for tracking.

**Goal:** The board on the desk shows the real departure-board UI, animated at
15 fps, driven by the spec's `DEMO_MODE` synthetic departures. That's every
canonical scene in both themes, with no network needed.

**Architecture:** The pure logic becomes an Arduino-free library, `lib/core/`:
colour maths, lane geometry, the scenery RNG, the board model, theme data, and
demo scenes. It is unit-tested on the PC under PlatformIO's `native` env.
Theme colours and demo scenes are **generated from the Python sources** by the
existing exporter, the same way sprites already are, so the simulator and the
firmware cannot drift. A thin Arduino layer in `src/` ports
`tools/board/render.py` line for line onto TFT_eSPI. It draws the frame in
horizontal bands through one reused 320x48 sprite, because a full-screen
buffer cannot be allocated on this chip.

**Tech Stack:** PlatformIO, `espressif32@7.1.3` (Arduino core 2.0.17),
TFT_eSPI 2.5.43, Unity for native tests (GCC 16 via WinLibs), Python 3.10 +
pytest for the exporter.

**Spec:** `docs/design/specs/2026-09-06-at-departure-board-design.md`
(§2 hardware, §4 architecture, §7 screen, §9 `DEMO_MODE`). Also read
`docs/hardware-notes.md`, which records measured facts that override the spec.
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

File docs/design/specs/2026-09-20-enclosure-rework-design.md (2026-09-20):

# Enclosure rework: side USB, a deeper bay, and a board sled

Date: 2026-09-20
Status: **superseded** by `2026-09-20-enclosure-wedge-design.md`, not built
Relates to: spec §11 (Enclosure), `docs/hardware-notes.md`

> Kept because §3 is the measurement that justifies the replacement: the DuPont
> stack does not fit this case at any orientation, which is why the enclosure is
> now modelled from scratch rather than reworked. The §2.1 board measurements
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

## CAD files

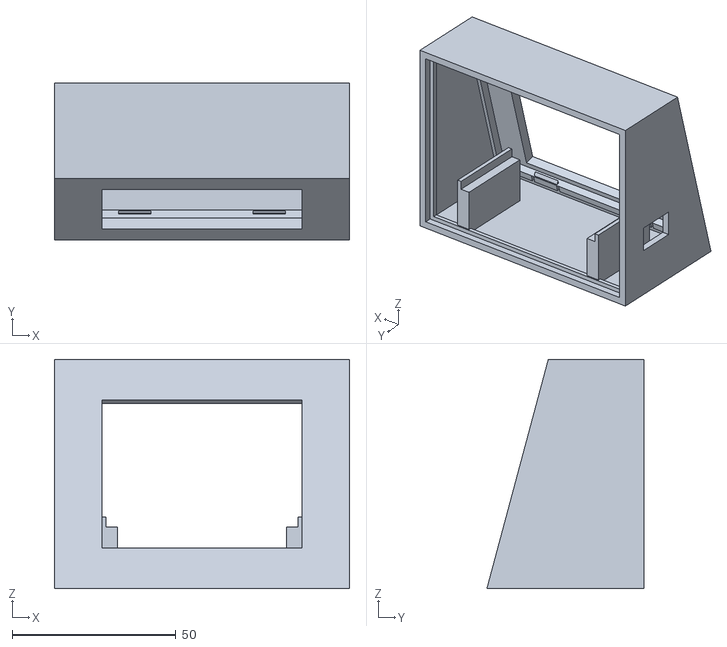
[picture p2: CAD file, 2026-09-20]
models/build/wedge_body.stl
90.0 x 48.0 x 70.0

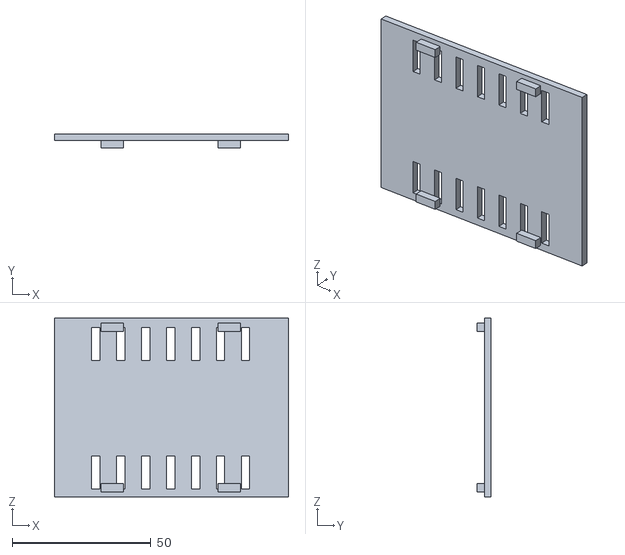
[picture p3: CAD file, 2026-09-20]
models/build/wedge_cover.stl
84.4 x 5.20 x 64.4

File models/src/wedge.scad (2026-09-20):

// AT departure board - raked wedge enclosure
// Design: docs/design/specs/2026-09-20-enclosure-wedge-design.md
//
// Render:
//   openscad -o models/build/wedge_body.stl  -D part=\"body\"  models/src/wedge.scad
//   openscad -o models/build/wedge_cover.stl -D part=\"cover\" models/src/wedge.scad
//
// Every dimension below is either measured or taken from the panel datasheet.
// Adjust a constant and re-render; nothing is hard-coded further down.

part = "both";          // "body" | "cover" | "both"
$fn = 64;

// ---------------------------------------------------------------- case shell
case_w   = 90;          // width
case_d   = 48;          // depth, set by the DevKit bay clearing the SD socket
case_h   = 70;          // height
wall     = 2.5;
rake     = 15;          // front face, degrees from vertical
face_t   = 3.6;         // = glass proud height, so the glass finishes flush

// ---------------------------------------------------------------- the panel
pcb_l    = 81.70;       // datasheet, long axis (horizontal in landscape)
pcb_w    = 50.00;       // short axis
pcb_t    = 1.60;
pcb_gap  = 0.40;        // total pocket clearance

aa_l     = 57.60;       // active area
aa_w     = 43.20;
aa_off   = 0;           // active-area centre vs PCB centre, + toward the pin end.
                        // 0 = the datasheet's centred reading. Set 5.80 if a
                        // print shows the image off toward the SD end.
ap_m     = 1.70;        // aperture margin round the image (see spec 4)

hole_d   = 3.2;         // panel mounting holes
hole_end = 2.90;        // from each short end   (pitch 75.90)
hole_side= 2.60;        // from each long edge   (pitch 44.80)
pin_d    = 2.9;         // locating pins, 0.3 under the hole
pin_h    = 1.4;         // just under pcb_t, so nothing protrudes

rim_w    = 2.5;         // pocket rim
rim_h    = 3.0;
tab_w    = 10.0;        // snap tabs retaining the panel
tab_lip  = 1.2;         // how far each tab overhangs the PCB
tab_gap  = 0.15;        // clearance over the PCB back face
tab_slot = 1.0;         // relief either side, so the tab can flex

// ---------------------------------------------------------------- the DevKit
dk_l     = 51.7;
dk_w     = 28.5;
dk_hous  = 16.3;        // housing well below the PCB
dk_pcb_t = 1.6;
dk_back  = 0.5;         // gap behind the board, to the cover
usb_w    = 14.0;
usb_h    = 9.0;

// ---------------------------------------------------------------- the cover
cov_t    = 2.5;
cov_gap  = 0.30;
ledge    = 1.5;
vent_w   = 3.0;
vent_n   = 7;

// ------------------------------------------------------------------ derived
face_len  = case_h / cos(rake);              // face runs the full height
pocket_l  = pcb_l + pcb_gap;
pocket_w  = pcb_w + pcb_gap;
pocket_u0 = (case_w - pocket_l) / 2;
pocket_v0 = (face_len - pocket_w) / 2;
pcb_u0    = (case_w - pcb_l) / 2;
pcb_v0    = (face_len - pcb_w) / 2;

ap_l      = aa_l + 2 * ap_m;
ap_w      = aa_w + 2 * ap_m;
ap_u0     = (case_w - ap_l) / 2 - aa_off;    // image centred on the case
ap_v0     = (face_len - ap_w) / 2;

floor_z   = wall;
dk_z      = floor_z + dk_hous;               // DevKit PCB underside
dk_y1     = case_d - cov_t - dk_back;        // DevKit back edge, just off the cover
dk_y0     = dk_y1 - dk_w;
dk_x0     = (case_w - dk_l) / 2;

op_x0 = wall;            op_x1 = case_w - wall;    // back opening
op_z0 = wall;            op_z1 = case_h - wall;

// Face frame: local (u, v, w) with w measured OUT of the front face.
face_m = [[1, 0,          0,         0],
          [0, sin(rake), -cos(rake), 0],
          [0, cos(rake),  sin(rake), 0],
          [0, 0,          0,         1]];

module on_face() { multmatrix(face_m) children(); }

// ------------------------------------------------------------------ profiles
module outer_profile() {
    polygon([[0, 0],
             [case_d, 0],
             [case_d, case_h],
             [case_h * tan(rake), case_h]]);
}

module cavity_profile() {
    f = face_t / cos(rake);                  // horizontal run of the face wall
    polygon([[floor_z * tan(rake) + f,        floor_z],
             [case_d + 10,                    floor_z],
             [case_d + 10,                    op_z1],
             [op_z1 * tan(rake) + f,          op_z1]]);
}

// extrude a (y,z) profile along x
module extrude_yz(x0, x1) {
    translate([x0, 0, 0]) rotate([90, 0, 90]) linear_extrude(x1 - x0) children();
}

// ---------------------------------------------------------------------- body
module shell() { extrude_yz(0, case_w) outer_profile(); }
module cavity() { extrude_yz(op_x0, op_x1) cavity_profile(); }

module aperture() {
    on_face() translate([ap_u0, ap_v0, -face_t - 20])
        cube([ap_l, ap_w, face_t + 30]);
}

module pocket_rim() {
    // +ov fuses the rim into the face rather than merely touching it
    ov = 0.6;
    on_face() translate([0, 0, -face_t - rim_h]) difference() {
        translate([pocket_u0 - rim_w, pocket_v0 - rim_w, 0])
            cube([pocket_l + 2 * rim_w, pocket_w + 2 * rim_w, rim_h + ov]);
        translate([pocket_u0, pocket_v0, -1])
            cube([pocket_l, pocket_w, rim_h + ov + 2]);
    }
}

// Snap tabs on the two long pocket edges. Cross-section in (v, w): a flat
// retaining face just behind the PCB, and a 45 deg lead-in so the panel presses
// straight in. Relief slots either side let each tab flex.
tab_back = -(face_t + pcb_t + tab_gap);     // retaining face
tab_deep = -(face_t + rim_h);               // rim inner face

module tab_at(v_edge, dir) {                // dir = +1 lower edge, -1 upper
    root = v_edge - dir * 0.6;              // overlap into the rim, so it fuses
    polygon([[root,                    tab_back],
             [v_edge + dir * tab_lip,  tab_back],
             [root,                    tab_deep]]);
}

module panel_tabs() {
    for (u = [pocket_u0 + pocket_l * 0.25, pocket_u0 + pocket_l * 0.75])
        on_face() translate([u - tab_w / 2, 0, 0]) rotate([90, 0, 90])
            linear_extrude(tab_w) {
                tab_at(pocket_v0, 1);
                tab_at(pocket_v0 + pocket_w, -1);
            }
}

module tab_relief() {
    for (u = [pocket_u0 + pocket_l * 0.25, pocket_u0 + pocket_l * 0.75],
         du = [-tab_w / 2 - tab_slot, tab_w / 2],
         v  = [pocket_v0 - rim_w - 1, pocket_v0 + pocket_w])
        on_face() translate([u + du, v, tab_deep - 1])
            cube([tab_slot, rim_w + 1, rim_h + 2]);
}

module locating_pins() {
    for (du = [hole_side, pcb_l - hole_side], dv = [hole_end, pcb_w - hole_end])
        on_face() translate([pcb_u0 + du, pcb_v0 + dv, -face_t - pin_h])
            cylinder(d = pin_d, h = pin_h + 0.6);
}

module dk_ledges() {
    for (x = [dk_x0 - 5, dk_x0 + dk_l])
        translate([x, dk_y0, floor_z - 0.6]) cube([5, dk_w, dk_z - floor_z + 0.6]);
    // upstands locating the board in x
    for (x = [dk_x0 - 5, dk_x0 + dk_l + 3.5])
        translate([x, dk_y0, dk_z]) cube([1.5, dk_w, dk_pcb_t + 1.5]);
}

module usb_opening() {
    translate([-5, (dk_y0 + dk_y1) / 2 - usb_w / 2, dk_z + dk_pcb_t + 1.6 - usb_h / 2])
        cube([wall + 10, usb_w, usb_h]);
}

module cover_ledge() {
    difference() {
        translate([op_x0 - 0.6, case_d - cov_t - ledge, op_z0 - 0.6])
            cube([op_x1 - op_x0 + 1.2, ledge, op_z1 - op_z0 + 1.2]);
        translate([op_x0 + ledge, case_d - cov_t - ledge - 1, op_z0 + ledge])
            cube([op_x1 - op_x0 - 2 * ledge, ledge + 2, op_z1 - op_z0 - 2 * ledge]);
    }
}

module body() {
    union() {
        difference() {
            shell();
            cavity();
            aperture();
            usb_opening();
        }
        intersection() {
            difference() {
                union() { pocket_rim(); panel_tabs(); locating_pins();
                          dk_ledges(); cover_ledge(); }
                tab_relief();
            }
            extrude_yz(-1, case_w + 1) outer_profile();
        }
    }
}

// --------------------------------------------------------------------- cover
module cover() {
    cw = op_x1 - op_x0 - 2 * cov_gap;
    ch = op_z1 - op_z0 - 2 * cov_gap;
    difference() {
        translate([op_x0 + cov_gap, case_d - cov_t, op_z0 + cov_gap])
            cube([cw, cov_t, ch]);
        // vents, low and high
        for (i = [0 : vent_n - 1], zf = [0.14, 0.86])
            translate([op_x0 + cw * (0.18 + 0.64 * i / (vent_n - 1)) - vent_w / 2,
                       case_d - cov_t - 1, op_z0 + ch * zf - 6])
                cube([vent_w, cov_t + 2, 12]);
    }
    // snap tabs catching the inside of the ledge
    for (x = [op_x0 + cw * 0.25, op_x0 + cw * 0.75], z = [op_z0 + 2, op_z1 - 5])
        translate([x - 4, case_d - cov_t - ledge - 1.2, z])
            cube([8, ledge + 1.2, 3]);
}

// ---------------------------------------------------------------------- main
if (part == "body")  body();
else if (part == "cover") cover();
else { body(); translate([0, 25, 0]) cover(); }

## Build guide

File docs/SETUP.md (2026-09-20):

# Build your own board

Start to finish: parts, case, wiring, flashing, and pointing the board at the
stops outside your own door. No prior ESP32 experience assumed — if you can copy
a file and run a command, you can do this.

Roughly an evening, most of which is the 3D print running in the background.

1. [Parts](#1-parts)
2. [Print the case](#2-print-the-case)
3. [Wire it up](#3-wire-it-up)
4. [Install the toolchain](#4-install-the-toolchain)
5. [Get an AT API key](#5-get-an-at-api-key)
6. [Fill in secrets.h](#6-fill-in-secretsh)
7. [Flash the board](#7-flash-the-board)
8. [First boot](#8-first-boot)
9. [Point it at your stops](#9-point-it-at-your-stops)
10. [Troubleshooting](#10-troubleshooting)

Want to see it before you buy anything? `python tools/simulate.py --all --show`
renders every board state on your PC. Have the hardware but no API key yet?
Skip to step 7 and flash `esp32_demo`.

## 1. Parts

| Part | Notes |
|---|---|
| **ESP32 DevKit (WROOM-32)** | Any standard dev board with a USB port. The unit here is an ESP32-D0WD-V3 — dual core, 4 MB flash, **no PSRAM needed**, CH340 USB-serial. An ESP32-S3 or C3 would need the pin numbers in `platformio.ini` revisited |
| **2.8" 320x240 SPI TFT** | [The panel used here](https://www.aliexpress.com/item/1005004557916570.html). The common red "2.8 TFT 240xRGBx320 V1.1" module with an SD slot and an unpopulated touch footprint. Touch is not used. Listings say ILI9341; the one received was an **ST7789**, and the firmware is configured for ST7789 — see [the display note](#the-panel-is-probably-an-st7789) below |
| **9 jumper wires** | Female-to-female if both sides have pins. Or solder direct, which is what fits a case best |
| **USB cable** | Data, not charge-only. This trips more people up than anything else on this list |
| **Printed case** (optional) | Designed for this build and in this repo — `models/build/wedge_body.stl` and `wedge_cover.stl`, ~60 g of filament. See the next section |

A USB phone charger runs it permanently; it draws a few hundred mA at most.

### The panel is probably an ST7789

These modules are sold as ILI9341 and frequently arrive with an ST7789
controller instead. The build in `platformio.ini` is configured for **ST7789**,
which is what the panel linked above turned out to be.

If your screen comes up blank, mirrored, or with inverted colours, that is the
first thing to check: swap `-DST7789_DRIVER=1` for `-DILI9341_DRIVER=1` in
`platformio.ini` and re-flash. [docs/hardware-notes.md](hardware-notes.md)
records how this was diagnosed.

## 2. Print the case

Two parts, both committed ready to slice — **you do not need OpenSCAD to print
them**:

```
models/build/wedge_body.stl
models/build/wedge_cover.stl
```

To change anything, edit the model and re-render:

```bash
openscad -o models/build/wedge_body.stl  -D 'part="body"'  models/src/wedge.scad
openscad -o models/build/wedge_cover.stl -D 'part="cover"' models/src/wedge.scad
```

A raked wedge, 90 x 48 x 70 mm, with a snap-on back cover. Print the body **on
its back face**: the raked front becomes a 15 deg overhang, so it needs no
support, and the visible face comes out clean.

Everything is a named constant at the top of `wedge.scad` — case size, rake,
aperture, board positions — so a different panel or DevKit is an edit and a
re-run, not a remodel. `pytest tests/test_models.py` re-checks the clearances the
design depends on and that each part is still a single manifold solid.

Dimensions for both boards are in [enclosure.md](enclosure.md), if you would
rather draw your own. The board is happy in any enclosure — the panel is readable
from across a room, so somewhere at eye level near the door is the point of the
thing.

## 3. Wire it up

Nine connections, no resistors, no level shifting.

| Display pin | ESP32 pin |
|---|---|
| VCC | 3V3 |
| GND | GND |
| CS | GPIO15 |
| RESET | GPIO4 |
| DC / RS | GPIO2 |
| SDI / MOSI | GPIO23 |
| SCK | GPIO18 |
| **LED** | **GPIO32** |
| SDO / MISO | GPIO19 |

The one that matters: **LED goes to GPIO32, not 3V3.** On GPIO32 the backlight
is PWM-able, which is what any dimming behaviour needs. Tied to 3V3 it is
full-brightness forever.

The SD card pins on the module are unused — leave them unconnected.

If you want different pins, they are build flags in `platformio.ini`
(`-DTFT_CS=15` and friends), not code.

**Fitting it all into the printed case** — which wires to push on first, what
length to buy, how the panel is retained, and what (if anything) needs soldering:
[assembly.md](assembly.md).

## 4. Install the toolchain

You need Python 3.9+ and [PlatformIO](https://platformio.org/install/cli). The
PlatformIO CLI downloads the ESP32 toolchain itself on first build.

```bash
python -m pip install -r requirements-dev.txt   # renderer + tools + tests
python -m pip install platformio                # or use the VS Code extension
```

Check it before you plug anything in:

```bash
python -m pytest        # the renderer tests: should be all green
pio test -e native      # the firmware logic tests, compiled for your PC
```

`pio test -e native` needs a host C++ compiler (`g++`, Xcode command line tools,
or MSVC). If you don't have one, skip it — it is not needed to build firmware
for the ESP32, only to run the logic tests on your own machine.

## 5. Get an AT API key

Free, and takes a few minutes.

1. Register at [dev-portal.at.govt.nz](https://dev-portal.at.govt.nz/).
2. Subscribe to **both** the GTFS product and the Realtime product — the same
   key must cover both. A key subscribed to only one gives you a board that
   shows scheduled times but never a live delay, or nothing at all.
3. Copy the primary key.

Keys are per-person and rate-limited; don't commit yours or share it.

## 6. Fill in secrets.h

```bash
cp src/secrets.example.h src/secrets.h
```

Then edit `src/secrets.h`:

```c
#define WIFI_SSID     "your-network"
#define WIFI_PASSWORD "your-password"
#define AT_API_KEY    "your-key"
```

`src/secrets.h` is gitignored and must stay that way — **never commit it.**
2.4 GHz WiFi only; the ESP32 has no 5 GHz radio, which is the usual reason a
board never connects in a house with a combined-band network name.

The demo build reads no credentials but still includes the header, so an
unedited copy is enough for `esp32_demo`.

## 7. Flash the board

**Auto-reset into the bootloader does not work on these boards.** You put the
chip into download mode by hand, first, every time:

> Hold **BOOT**. Press and release **EN**. Release **BOOT**.

The screen won't change — that's expected. Then, immediately:

```bash
pio run -e esp32 -t upload        # the live board
```

or, with no API key and no WiFi:

```bash
pio run -e esp32_demo -t upload   # every board state, played in real time
```

PlatformIO auto-detects the serial port. With more than one board plugged in,
name it: `--upload-port COM8` on Windows, `--upload-port /dev/ttyUSB0` on Linux,
`/dev/cu.usbserial-*` on macOS.

The upload runs at 115200 baud on purpose: at 460800 the CH340 link drops mid-
flash. The firmware starts on its own once the upload finishes.

If this becomes tiresome, a 1 µF capacitor between EN and GND restores normal
auto-reset.

## 8. First boot

```bash
pio device monitor      # 115200 baud
```

A healthy live boot looks like this:

```
wifi: connected, ip 192.168.1.42 rssi -54
time: 1789412345
portal: listening on :80
BOOT-OK live
resolve 8213 -> ...  toward 1060 -> ...  routes 1
```

**Write down that IP** — it's the setup page. The board also appears as a new
ESP32 client in your router's device list, and it's worth giving it a DHCP
reservation there so the address doesn't move.

The panel should light up within a couple of seconds and start drawing. Lanes
fill in as the first fetch completes.

## 9. Point it at your stops

Open `http://<board-ip>/` in a browser on the same network.

The page has the location name shown on the panel, the theme, and up to **four**
watches. Each watch is four fields:

| Field | What to put in it |
|---|---|
| **Label** | What this lane is called on the panel — `to Wynyard Quarter`, `to work`, `city trains`. Up to 24 characters; the panel font is ASCII, so no macrons |
| **Stop code** | The number printed on the bus stop pole or listed on AT's site, e.g. `8213`. Hit **Check** and the board asks AT and shows you the stop's real name — if that isn't the stop you meant, you have the wrong code |
| **Route** | A route number to pin, e.g. `20`. Leave empty for "anything that stops here" |
| **Toward stop** | The stop code of somewhere further along in the direction you travel |

Then **Save and restart**. The board writes the config to flash and reboots;
it's back in a couple of seconds.

### Choosing the two tricky fields

**Route** — pin it when your stop also serves things you'd never board. A stop
served by the `20` you take and the `22R` you don't will otherwise show you a
`22R` that's irrelevant. A stop where anything going that way is useful — most
train platforms — should leave it empty. Empty is also what carries a rail watch
through a line rename, which Auckland does periodically.

**Toward stop** — this is *not* a direction like "inbound". Pick any stop
further along the route in the direction you'd travel; the board works out the
direction from it at every refresh, which is why a renumbered direction can't
silently flip your lane. Find the code the same way you found your own stop:
look up the route, follow it a few stops the way you go, take that pole number.
[docs/at-api-notes.md](at-api-notes.md) explains why it works this way.

If a watch can't prove its direction, the lane shows **check config** and
deliberately shows no departures rather than possibly-wrong ones.

### Themes

`transit` is the clean default. `ghibli` is softer, with different scenery and
palette. Switching themes applies immediately — no reboot.

Preview both on your PC before choosing:

```bash
python tools/simulate.py --scene two_up --theme ghibli --show
```

### Changing WiFi later

WiFi credentials and the API key are compiled in, not in the setup page, so
changing networks means editing `src/secrets.h` and re-flashing (step 7). The
stops and theme survive a re-flash — they live in NVS, not in the firmware
image.

## 10. Troubleshooting

| Symptom | Cause |
|---|---|
| `Wrong boot mode detected (0x13)` | The BOOT/EN dance didn't take. Hold BOOT, tap EN, release BOOT, then run upload — in that order, without letting go early |
| `No serial data received` | Released BOOT before EN, or a charge-only USB cable |
| `No more data to read from the serial port` | Upload speed too high for a CH340 link. The repo already pins 115200; don't raise it |
| No port found at all | Missing USB-serial driver (CH340 or CP2102 depending on your board), or a charge-only cable |
| `wifi: FAILED status 1` repeatedly | Wrong SSID or password in `src/secrets.h`, or a 5 GHz-only network |
| Screen stays black, board otherwise fine | Backlight not on GPIO32, or wrong driver — try `-DILI9341_DRIVER=1` |
| Colours inverted or mirrored | Wrong driver for your panel, as above. `-DTFT_INVERSION_OFF=1` and `-DTFT_RGB_ORDER=TFT_BGR` are the other two knobs |
| Lanes empty, serial shows `HTTP 401` or `403` | API key wrong, or not subscribed to both GTFS **and** Realtime |
| Times show but never a live delay | Key isn't subscribed to the Realtime product |
| A lane says **check config** | That watch's direction couldn't be derived — check its Toward stop is really further along the route in the direction you travel |
| A lane says **none tonight** | Correct and working: nothing more is scheduled today |
| Times drift then say **stale** | The board lost the network or the clock. It retries on its own; the dimmed panel is it telling you the numbers are old |

Still stuck? Open an issue with the serial log from boot — it says a lot.

## Where things live

- [../README.md](../README.md) — what the board is and how the repo is laid out.
- [hardware-notes.md](hardware-notes.md) — measured heap, the flashing dance,
  the ST7789 discovery.
- [at-api-notes.md](at-api-notes.md) — how AT's API actually behaves. Read this
  before touching the network code.
- [../CONTRIBUTING.md](../CONTRIBUTING.md) — running the tests, the golden
  renders, what a good change looks like.

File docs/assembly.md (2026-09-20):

# Assembly — wiring and fitting the printed case

Physical build, start to finish. The electrical side is nine wires and no
components; most of the fiddle is mechanical.

Dimensions are in [`enclosure.md`](enclosure.md); why the case is shaped this way
is in [`design/specs/2026-09-20-enclosure-wedge-design.md`](design/specs/2026-09-20-enclosure-wedge-design.md).

## What you need

| | |
|---|---|
| Printed `wedge_body.stl` and `wedge_cover.stl` | from `models/build/` |
| 2.8" 320×240 SPI panel | ST7789, no touch |
| ESP32 WROOM-32 DevKit, 30-pin | USB-C on this build |
| **9 jumper wires** | Female at **both** ends, ~100 mm — see below if you only have M-F |
| USB-C cable and a 5 V supply | it is permanently powered |

**They must be female at both ends.** Both boards present male pins, and
male-to-female jumpers cannot be chained into a female-to-female one: join two
end to end and you get `F —[M·F]— M`, still female at one end and male at the
other. Adding a third does not change it. The only way to bridge two male
headers with M-F jumpers is to get rid of one set of male pins — see below.

**100 mm is the right length.** Measured against the model, the runs from a
DevKit pin to a panel pin are 24–65 mm straight-line, 31–84 mm once bends and
routing are allowed for. 100 mm covers the longest with slack; the excess on the
short runs coils into the void beside the DevKit.

### If you only have male-to-female

Both boards normally arrive with their headers already soldered, so the male pins
are a given. **Do not desolder the panel's 14-pin header to get around this** —
removing 14 through-plated pins without lifting a pad is far harder than anything
else in this build, and there is no need.

**Buy nine F-F jumpers.** A few dollars. No soldering anywhere, and §4 becomes the
whole job. If you can wait for the post, stop here.

**Or make nine F-F from eighteen M-F.** Cut each jumper roughly in half, keep the
female halves, and splice two of them together — solder the bare ends, slide
heatshrink over the joint. Nine splices and you have exactly what you need.

This is the easiest soldering in the whole project: wire to wire, in free air,
nothing to overheat and no pads to lift. It is considerably more forgiving than
fitting a header, and it touches neither board.

| | F-F bought | Spliced from M-F |
|---|---|---|
| Soldering | none | 9 wire-to-wire joints |
| Jumpers used | 9 | 18 |
| Risk to the boards | none | none |
| Length to aim for | 100 mm | cut each half to ~50 mm |

Runs are 24–65 mm straight-line and 31–84 mm routed either way, since both keep
the panel's existing header. Aim for about 100 mm end to end and coil the slack
beside the DevKit.

Whatever you do, do not rely on twisted-and-taped joints. This board is powered
continuously and lives behind a closed cover.

The printed parts do not change either way.

## 1. Soldering — probably none

Both boards usually ship with headers fitted. Check before you buy an iron.

**If the panel's 14-pin header is loose** (uncommon — most ship fitted), solder it to the **back** of
the panel, plastic spacer against the PCB, long pins pointing **away from the
glass**. Solder all 14 even though only 9 are used — the outer pins carry the
mechanical load when you push jumpers on.

Pin protrusion is not critical. The case is drawn around the 7.4 mm measured on
this build, but a standard 11.5 mm header still leaves 5.5 mm of clearance behind
the panel.

**If the DevKit's headers are loose**, solder them so the pins protrude from the
side **opposite** the chip. That is the normal way round, and it is what lets the
board sit component-side-up with its pins pointing down into the well.

Nothing else is soldered.

## 2. Fit the panel

The panel drops into the pocket in the raked front face, glass through the
aperture, and is held by **four snap tabs** on the long edges.

1. Check the pocket for stringing or elephant's foot and clean it up. It is
   82.1 × 50.4 against an 81.70 × 50.00 board, so there is only 0.2 mm a side.
2. Sit the panel on the four **Ø2.9 locating pins** — they pass into the panel's
   own Ø3.2 mounting holes and set its position. The pins are 1.4 mm tall against
   a 1.6 mm board, so nothing stands proud.
3. Press the panel straight down until the four tabs click over its back face.
   Each tab has a 45° lead-in, so it should need thumb pressure, not tools.

To remove it, push the tabs outward with a thin blade and lift one edge.

**It fits either way round.** The panel and pocket are both symmetric, and the
glass and image are concentric with the PCB, so the screen lands centred
whichever end the header is at. Match the firmware to it: `setRotation(1)` for
pins on the right, `setRotation(3)` for pins on the left — both give a clean
320×240 landscape, per [`hardware-notes.md`](hardware-notes.md).

> If the tabs print too tight or snap off, the fallback is four dabs of hot glue
> at the corners of the PCB, clear of the glass. The locating pins are doing the
> accurate work; the tabs only stop it falling back into the case.

## 3. Fit the DevKit

It sits in the deep lower rear, **component side up, pins pointing down** into
the housing well.

1. Feed the USB-C end toward the **left flank**, through the 14 × 9 opening.
2. Lower the board onto the two ledges at its short ends. The upstands either
   side locate it; the board underside sits 18.8 mm above the inner floor.

Component-side-up is deliberate: BOOT, EN and the chip all face the open back, so
lifting the cover puts a finger on them. There are no access holes anywhere in
the case, and you will need those buttons on every flash — see §5.

## 4. Wire it up

Nine connections. No resistors, no level shifting.

| Panel pin | ESP32 | Note |
|---|---|---|
| 1 VCC | 3V3 | |
| 2 GND | GND | |
| 3 CS | GPIO15 | |
| 4 RESET | GPIO4 | |
| 5 DC / RS | GPIO2 | |
| 6 SDI / MOSI | GPIO23 | |
| 7 SCK | GPIO18 | |
| 8 **LED** | **GPIO32** | **not 3V3** — see below |
| 9 SDO / MISO | GPIO19 | |

The panel's nine signals are **pins 1–9, a contiguous run** from the VCC end. Pins
10–14 are the touch controller and stay unconnected, as do the four SD pins at
the opposite end of the board.

**LED goes to GPIO32, not 3V3.** On GPIO32 the backlight is PWM-able, which is
what any dimming behaviour needs. Tied to 3V3 it is full brightness forever.

Working order that avoids fighting yourself:

1. Connect all nine at the **panel** first, while the back is wide open and you
   can see the silkscreen — pushing jumpers on, or soldering them in. Start at VCC
   and work along; they are adjacent, so a miscount is easy to spot.
   Ribbon-style jumpers come joined in a strip; keeping pins 1-9 as one uncut
   ribbon makes a miscount almost impossible.
2. Route each wire down the inside of the back, toward the DevKit.
3. Push them onto the **DevKit** last, checking each against the table.
4. Coil the slack into the space beside the DevKit, between the board and the
   right-hand wall. Keep it clear of the USB opening.

On most 30-pin boards the majority of these GPIOs land on one header row, with
GPIO32 on the other — so do the long row first and the single stray last. Read
your board's silkscreen rather than trusting a pinout diagram; they vary.

If you want different pins, they are build flags in `platformio.ini`
(`-DTFT_CS=15` and friends), not code.

## 5. Cover, and flashing

Fit the cover last. It drops into the ledge around the back opening and snaps in.
The vents are not decoration — the ESP32 runs warm and holds WiFi and TLS up
continuously.

**Take the cover off to flash.** `docs/hardware-notes.md` records that auto-reset
into the bootloader does not work on this board, so every upload needs:

1. Hold **BOOT**
2. Press and release **EN**
3. Release **BOOT**
4. `pio run -e esp32 -t upload`

Both buttons face the open back, so this is one hand and no disassembly beyond
the cover.

A 1 µF capacitor between EN and GND makes auto-reset work and removes the step
for good. If you are comfortable with that solder joint it is worth doing once.

## 6. First power-up

Power it over USB-C before committing to the cover. Expect the backlight on and
something on screen within a second or two; the first fetch waits for WiFi
association, which takes a few seconds more.

If the screen stays dark, check LED → GPIO32 first. If it lights but shows
nothing, check DC → GPIO2 and CS → GPIO15. If the colours look wrong or the image
is a photo negative, that is a driver setting rather than wiring —
[`hardware-notes.md`](hardware-notes.md) has a table of exactly which wrong
setting produces which symptom.

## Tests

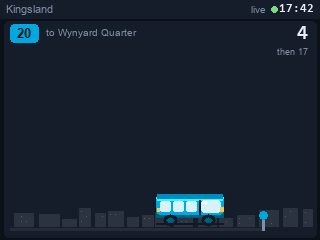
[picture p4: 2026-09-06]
tests/golden/single.png

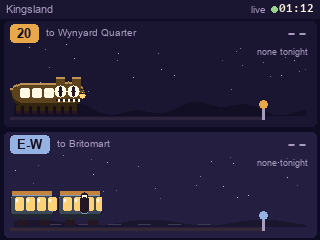
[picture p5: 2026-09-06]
tests/golden/ghibli__empty.png

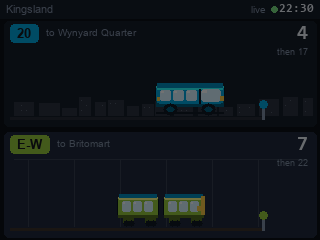
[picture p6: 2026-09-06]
tests/golden/dimmed.png

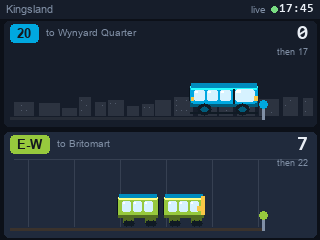
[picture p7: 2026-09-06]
tests/golden/arriving.png

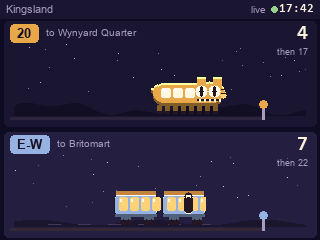
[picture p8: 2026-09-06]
tests/golden/ghibli__two_up.png

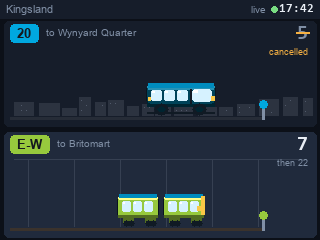
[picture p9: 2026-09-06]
tests/golden/cancelled.png

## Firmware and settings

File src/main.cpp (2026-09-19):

// Firmware entry point. DEMO_MODE plays the canonical scenes from
// tools/board/scenes.py, counting down in real time; otherwise this is the
// live data path (spec section 9).
#include <Arduino.h>
#include <TFT_eSPI.h>
#include <esp_heap_caps.h>
#include <time.h>

#include "backlight.h"
#include "ui.h"

#ifdef DEMO_MODE
#include "demo.h"
#else
#include <WiFi.h>

#include "config.h"
#include "fetcher.h"
#include "live.h"
#include "portal.h"
#include "secrets.h"
#endif

namespace {

TFT_eSPI tft;
Ui ui(tft);

constexpr uint32_t FRAME_MS = 1000 / 15;  // 15 fps, spec section 5
constexpr uint32_t REPORT_MS = 5000;

#ifdef DEMO_MODE
void report(uint32_t now, uint32_t frames, uint32_t draw_ms_total, uint32_t since) {
  Serial.printf("fps %.1f  draw %lums  heap %u  largest %u  min-ever %u\n",
                frames * 1000.0f / (now - since),
                static_cast<unsigned long>(draw_ms_total / frames), ESP.getFreeHeap(),
                heap_caps_get_largest_free_block(MALLOC_CAP_8BIT), ESP.getMinFreeHeap());
}

Board board_now(uint32_t ms, int64_t) { return demo_board(ms); }
#else
Snapshot snap;  // static storage: a Snapshot is far too big for a task stack

// Reuses the snapshot board_now() already copied this frame - never a second
// fetcher_snapshot() call, which would be one more memcpy under the mutex.
void report(uint32_t now, uint32_t frames, uint32_t draw_ms_total, uint32_t since) {
  char rows[48] = "";
  size_t off = 0;
  for (uint8_t i = 0; i < snap.n_watches && off + 4 < sizeof rows; i++) {
    off += snprintf(rows + off, sizeof(rows) - off, "%s%u", i ? "/" : "",
                    static_cast<unsigned>(snap.watches[i].n_rows));
  }
  Serial.printf("fps %.1f  draw %lums  heap %u  largest %u  min-ever %u  rows %s\n",
                frames * 1000.0f / (now - since),
                static_cast<unsigned long>(draw_ms_total / frames), ESP.getFreeHeap(),
                heap_caps_get_largest_free_block(MALLOC_CAP_8BIT), ESP.getMinFreeHeap(), rows);
}

Board board_now(uint32_t, int64_t now) {
  fetcher_snapshot(&snap);  // a memcpy under the mutex, never a network wait
  return build_board(snap, config_watches(), config_location(), now, config_theme());
}
#endif

}  // namespace

void setup() {
  Serial.begin(115200);
  backlight_begin();
  tft.init();
  tft.setRotation(1);
  if (!ui.begin()) {
    Serial.println("FATAL: band sprite allocation failed");
    tft.fillScreen(TFT_RED);
    for (;;) delay(1000);
  }

#ifdef DEMO_MODE
  Serial.println("BOOT-OK demo");
#else
  WiFi.mode(WIFI_STA);

  // Before fetcher_begin(): that reads config_n_watches().
  config_begin();
  WiFi.begin(WIFI_SSID, WIFI_PASSWORD);

  bool wifi_ok = false;
  for (int i = 0; i < 20; i++) {
    if (WiFi.status() == WL_CONNECTED) {
      wifi_ok = true;
      break;
    }
    Serial.printf("wifi: status %d\n", WiFi.status());
    delay(1000);
  }
  if (wifi_ok) {
    Serial.printf("wifi: connected, ip %s rssi %d\n", WiFi.localIP().toString().c_str(),
                  WiFi.RSSI());
  } else {
    Serial.printf("wifi: FAILED status %d\n", WiFi.status());
  }

  // NTP is started here and waited for only as a courtesy to the log: the
  // fetcher retries both WiFi and the clock on its own.
  configTime(0, 0, "pool.ntp.org");  // UTC - nztime does the local conversion
  bool time_ok = false;
  if (wifi_ok) {
    for (int i = 0; i < 15; i++) {
      if (time(nullptr) >= CLOCK_SET_AFTER) {
        time_ok = true;
        break;
      }
      delay(1000);
    }
  }
  if (time_ok) {
    Serial.printf("time: %lld\n", static_cast<int64_t>(time(nullptr)));
  } else {
    Serial.println("time: not synced yet");
  }

  // Every network call from here on happens on the fetch task: core 0, 16 KB
  // of stack. The loop task does nothing but draw (spec 8).
  fetcher_begin();
  portal_begin();

  Serial.println("BOOT-OK live");
#endif
}

void loop() {
  static uint32_t frames = 0, draw_ms_total = 0, last_report = 0;
  static uint32_t next_frame = 0;

  const uint32_t start = millis();
  if (next_frame == 0) next_frame = start;

#ifdef DEMO_MODE
  static int last_scene = -1;

  const int scene = static_cast<int>((start / DEMO_SCENE_MS) % demo_scene_count());
  if (scene != last_scene) {
    const Board b = demo_board(start);
    Serial.printf("scene %s  theme %u\n", demo_scene(scene).name, b.theme);
    last_scene = scene;
  }
#endif

  // time(nullptr) is whatever the RTC has. Before NTP lands it reads some
  // small value near the 1970 epoch, but every watch is still
  // WatchState::Starting until the fetcher's first successful resolve, so
  // build_board skips its rows regardless (live.cpp: `if (lw.state !=
  // WatchState::Ok) continue;`) - the lanes just say "starting" and no
  // countdown is drawn from the bad clock.
  const int64_t now = time(nullptr);
  ui.draw(board_now(start, now), start);

  const uint32_t took = millis() - start;
  frames++;
  draw_ms_total += took;
  if (start - last_report >= REPORT_MS) {
    report(start, frames, draw_ms_total, last_report);
    frames = 0;
    draw_ms_total = 0;
    last_report = start;
  }

  // Pace against an absolute deadline rather than delaying by (FRAME_MS -
  // took): a relative delay drifts by the draw time every frame, and over a
  // long-running board that adds up. If we have fallen behind (a slow frame,
  // or a Serial.printf report), snap the deadline to now instead of trying to
  // catch up in one step.
  next_frame += FRAME_MS;
  const uint32_t now_ms = millis();
  if (static_cast<int32_t>(next_frame - now_ms) > 0) {
    delay(next_frame - now_ms);
  } else {
    next_frame = now_ms;  // we are behind; do not spiral
  }
}

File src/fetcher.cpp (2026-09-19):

#include "fetcher.h"

#include <Arduino.h>
#include <ArduinoJson.h>
#include <WiFi.h>
#include <esp_heap_caps.h>
#include <freertos/FreeRTOS.h>
#include <freertos/semphr.h>
#include <freertos/task.h>
#include <string.h>
#include <time.h>

#include "at_api.h"
#include "at_client.h"
#include "freshness.h"
#include "config.h"
#include "secrets.h"

// The three loops of spec 5, folded into one task so that only one thing ever
// holds a TLS session: schedule every 15 minutes (and on a date rollover),
// realtime every 30 s while something is close and every 2 minutes otherwise,
// and stop/route resolution once, lazily, per watch.
//
// Everything decision-shaped - which direction is city-bound, which rows to
// keep, which delay to believe - already lives in lib/core and is tested on a
// laptop. What is left here is I/O, cadence and the error surfaces of spec 8.

namespace {

// --- cadences (spec 5) ------------------------------------------------------
// SCHEDULE_PERIOD_S, RT_FAST_S and RT_SLOW_S live in freshness.h, next to the
// rule that decides which of them is published.
constexpr int32_t RT_FAST_WITHIN_S = 30 * 60;
constexpr int32_t BACKOFF_CAP_S = 300;
constexpr int32_t NO_LINK_RETRY_S = 5;   // no WiFi or no clock yet
constexpr int32_t RESOLVE_RETRY_S = 60;  // a 400/401 must not become a request storm
constexpr int32_t SCHEDULE_RETRY_S = 60; // after an inconclusive refresh: soon, not every tick

// --- buffer sizes -----------------------------------------------------------
constexpr int MAX_SCHED_ROWS = 48;  // 3 hours at a busy stop, both windows
constexpr int MAX_TRIP_STOPS = 96;  // a full rail line end to end, with room
constexpr int MAX_ENTITIES = 32;    // 24 asked for; the tripid filter overshoots
constexpr int MAX_RT_IDS = 24;
constexpr int RT_PER_WATCH = 6;
constexpr int MAX_RAIL = 12;  // 8 rail routes today, both sides of the rename
constexpr int MAX_PINNED = 2;

// at_get returns an HTTP status or a negative; this is the one extra outcome
// the callers need: the server said 200 and the data array was empty.
constexpr int AT_EMPTY = 204;

// --- state ------------------------------------------------------------------
// Every buffer below is file scope. A Snapshot on its own is larger than the
// Arduino loop task's whole stack, and what a TLS session needs is most of
// what this task's 16 KB has.

SemaphoreHandle_t g_lock = nullptr;
Snapshot g_published;  // what the render loop copies
Snapshot g_work;       // what this task mutates

struct Resolved {
  char stop_id[STOP_ID_LEN];
  char target_stop_id[STOP_ID_LEN];
  char route_ids[MAX_PINNED][ROUTE_ID_LEN];
  int n_routes;
  bool resolved;
  int64_t next_try;    // resolution is rate limited; see RESOLVE_RETRY_S
  int64_t next_sched;  // when this watch's schedule is next due
  CivilDate sched_date;
};
Resolved g_res[MAX_WATCHES];
// Per watch, the epoch of its last conclusive schedule refresh. The board is
// only as fresh as its stalest schedule (board_last_ok): realtime news for one
// watch must not keep another, whose schedule keeps failing, looking live.
int64_t g_sched_ok_at[MAX_WATCHES];

RouteInfo g_rail[MAX_RAIL];
int g_n_rail = 0;
bool g_rail_loaded = false;

RouteInfo g_routes[8];  // the answer to one filter[route_short_name]
StopTripRow g_rows[MAX_SCHED_ROWS];
// The (route, direction) pairs of the watch being refreshed. Shared across
// watches like g_rows: they are only read inside the refresh that fills them.
RouteDir g_pairs[MAX_ROUTE_DIRS];
bool g_pair_failed[MAX_ROUTE_DIRS];  // its trips/{id}/stops did not answer 200
char g_log[200];  // the "dirs" line: six pairs of up to ~26 characters
// The rows a schedule refresh is about to replace, so what realtime already
// said about them can be carried across (carry_realtime). File scope, not stack.
LiveRow g_old_rows[MAX_ROWS];
TripStop g_stops[MAX_TRIP_STOPS];
RtEntity g_ents[MAX_ENTITIES];
const char* g_ids[MAX_RT_IDS];  // pointers into g_work's own rows
FetchWindow g_win[2];

JsonDocument g_doc;
JsonDocument g_filter;
char g_url[1536];  // 24 trip ids of up to 47 characters, plus the base

int32_t g_backoff = 0;  // 0 when not backing off
bool g_time_started = false;
WatchState g_logged[MAX_WATCHES];

// Folded over every request in a pass, to decide backoff once.
struct Pass {
  bool backoff;
};
Pass g_pass;

// News and failures, in the order they happen. News is only a conclusive
// schedule refresh or a realtime 200: a resolve or a rail lookup that happens
// to 200 is not news about departures, and an inconclusive refresh is not
// evidence of anything - counting either would let a board drain while it
// still looked fresh. A failure is any answer but 200 or 404, or no link.
Freshness g_fresh;

// --- plumbing ---------------------------------------------------------------

void publish() {
  xSemaphoreTake(g_lock, portMAX_DELAY);
  memcpy(&g_published, &g_work, sizeof g_published);
  xSemaphoreGive(g_lock);
}

// Spec 8: 429, 5xx and anything that never reached the server. A 400 or a 401
// is a configuration fault - backing off would only delay the fix.
bool should_backoff(int status) {
  return status == AT_TRANSPORT_ERROR || status == AT_PARSE_ERROR || status == 429 || status >= 500;
}

// One GET against g_url with the given response filter. The doc and the filter
// are file scope so neither lands on the stack next to a TLS session.
int get(void (*make_filter)(JsonDocument&)) {
  g_filter.clear();
  make_filter(g_filter);
  const int status = at_get(g_url, g_doc, g_filter);
  if (should_backoff(status)) g_pass.backoff = true;
  if (status != 200 && status != 404) freshness_failure(g_fresh);
  return status;
}

bool ensure_wifi() {
  if (WiFi.status() == WL_CONNECTED) return true;
  static uint32_t last_begin = 0;
  const uint32_t ms = millis();
  if (last_begin == 0 || ms - last_begin > 15000) {  // let an attempt finish first
    WiFi.mode(WIFI_STA);
    WiFi.begin(WIFI_SSID, WIFI_PASSWORD);
    last_begin = ms;
  }
  return false;
}

bool ensure_time() {
  if (!g_time_started) {
    configTime(0, 0, "pool.ntp.org");  // UTC; nztime does the local conversion
    g_time_started = true;
  }
  return time(nullptr) >= CLOCK_SET_AFTER;  // the same line format_clock draws
}

// A 401 is not transient and is not backed off, so both the resolution and the
// schedule retries are rate limited by hand: a wrong key must cost one request
// a minute, not one every 30 seconds.
void set_all(WatchState s, int64_t now) {
  for (int i = 0; i < g_work.n_watches; i++) {
    g_work.watches[i].state = s;
    g_res[i].next_try = now + RESOLVE_RETRY_S;
    if (g_res[i].next_sched < now + RESOLVE_RETRY_S) g_res[i].next_sched = now + RESOLVE_RETRY_S;
  }
}

// --- badges and colours -----------------------------------------------------

const RouteInfo* rail_route(const char* route_id) {
  for (int i = 0; i < g_n_rail; i++) {
    if (strcmp(g_rail[i].route_id, route_id) == 0) return &g_rail[i];
  }
  return nullptr;
}
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

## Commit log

2026-09-06 Design: AT departure board for ESP32 + ILI9341
    Verified AT's GTFS v3 and realtime-compat endpoints against the dev portal
    rather than guessing: stoptrips returns departure_time, trip_id, route_id and
    direction_id in one call, and the realtime feed accepts a tripid filter, which
    is what keeps the whole feed out of ESP32 heap.
    Includes the layout mockup renderer used to choose the approach-lane design,
    and notes on the one unresolved gap (stop_code -> hashed stop_id).
2026-09-06 Verify AT API against live endpoints; correct the design
    Probed every endpoint with a real key rather than trusting the portal docs.
    Five behaviours differ from what is documented, each of which would have
    shipped as a defect:
    - filter[stop_code] works (undocumented), so the fallback that streamed every
    stop in Auckland is dropped entirely
    - stoptrips returns 404 for "no services in this window", not just for an
    unknown stop. The first draft re-resolved cached stop ids on any 404, which
    would have re-resolved every stop every night once services stopped
    - stop_time_update is a single object, not the documented array, and describes
    the vehicle's next stop rather than ours, so trip-le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
2026-09-06 Plan: display layer and sprite asset pipeline
    Splits the build so the visual layer can be designed and proven on a laptop
    before any hardware is involved. Ends with golden-tested renders of every
    board state and sprites exported as 4bpp indexed C arrays, which is what
    stops the simulator and the firmware drifting apart.
    Firmware and network layers follow in a second plan.
2026-09-06 Add colour roles and pixel-art vehicle sprites
    Sprites name roles, not colours, so one bus sprite renders in whatever
    colour the route is. Row-width tests catch miscounted pixel art at author
    time rather than as a visual glitch - which they promptly did, catching the
    train at 46 wide against a declared 48.
    Black is treated as absent: HUIA's #000000 would be invisible on our ground.
2026-09-06 Add board model
    Mirrors the struct the firmware builds after the schedule/realtime merge,
    so simulator and device share vocabulary. Departures self-sort; a board
    outside 1..4 watches is rejected at construction.
2026-09-06 Add approach-lane geometry
    Pure integers in, rectangles out, so the core idea - that a vehicle's x
    position is its time to arrival - is exhaustively testable without
    rendering anything. Position is monotonic and clamps at both ends.
2026-09-06 Add board renderer and canonical scenes
    Scenes are the single list of states that goldens, demos and the firmware's
    DEMO_MODE all draw from, so a state cannot be exercised in one and
    forgotten in another. Includes the two states boards usually get wrong:
    1am with nothing left, and a cancelled service.
2026-09-06 Freeze golden images for every board state
    Byte-exact comparison, so an unintended render change fails loudly rather
    than drifting. Changing a render means regenerating goldens in the same
    commit, which the failure message says explicitly.
    Inspecting the goldens before freezing them caught one real problem: a 2px
    strikethrough is invisible from across the room, which is the distance this
    board is read from. Cancelled services now say "cancelled" in amber where
    "then 20" would go, so the signal survives the viewing distance.
2026-09-06 Plan: make scenery reproducible in C
    Task 4 drew its stars and skyline from random.Random. The firmware animates
    the 1px bob by repainting the sprite's bounding box, that box overlaps the
    scenery, so the erase has to redraw it — which means the ESP32 must place the
    same stars the renderer did. A Mersenne Twister does not port to C.
    Swaps it for a 32-bit LCG with the high bits taken (an LCG's low bits would
    draw the stars in diagonal stripes), and pins the sequence in a test so the
    firmware has something to check itself against. Also lifts the hill profile
    into a pure function of dx, so the firmware can precompute a byte table per
    lane instead of calling sin() per column.
    Five lines now;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
2026-09-13 Re-verify against the live API after CRL; derive direction instead of storing it
    CRL opened today. Re-probing produced one vindication and one real defect.
    Vindicated: leaving rail routes unpinned worked exactly as designed. WEST-201
    stopped running at Kingsland, E-W-201 took over, and nothing needed
    reconfiguring or reflashing. Stop id hashes survived the GTFS version change
    and the bus was untouched.
    Broken: direction_id inverted. Pre-CRL, direction 0 at Kingsland meant
    Swanson -> Britomart, toward the city. Post-CRL direction 0 runs Manukau ->
    Swanson, away from it; city-bound is now direction 1. Confirmed against the
    trips' own stop lists, not by reading headsigns:
    dir 0 after Kings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
2026-09-15 Measure the firmware budget on real hardware; find a silent-failure bug
    Ran a throwaway spike on the actual ESP32 before designing the firmware
    around estimates. Three results.
    The memory budget holds with about 2x headroom. TLS costs ~44KB against a
    40KB estimate; with the 35KB sprite held and TLS live there is still 94KB
    contiguous free, and the lowest heap across a full fetch-and-parse run was
    150,932 bytes. No leaks. Direct-to-AT stands; no proxy needed.
    Free heap is 351KB but the largest contiguous block is only 114KB, because
    the ESP32 heap is split across regions. A full-screen 320x240x16bpp
    framebuffer needs 153,600 bytes in one piece and therefore cannot be
    allocated at all. The p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
2026-09-15 Verify the full data path end-to-end on hardware
    One pass on the board with the sprite held throughout: schedule fetched and
    parsed, realtime delays merged, both transfer encodings handled by the
    runtime branch.
    A. stoptrips without de-chunking -> 0 departures (silent failure, again)
    B. stoptrips with de-chunking -> 11 departures
    C. realtime ?tripid= -> 4 entities, delays -6 +16 -52 +66s
    The conditional picked chunked for GTFS and content-length for realtime
    inside the same run, which is exactly what the firmware needs. Lowest heap
    across the pass: 151,032 bytes.
    The delays are live data, and they make the case for the whole project:
    one train 52s early, another 66s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
2026-09-18 Bring up the display: the panel is an ST7789, not an ILI9341
    The screen was blank because the board was still running the heap spike,
    which never touches the display. A throwaway bring-up spike (spike/display/)
    then found the real problem: the red "2.8in TFT 240xRGBx320 V1.1" module is
    sold as ILI9341 but carries an ST7789.
    Each wrong setting has a distinct look, recorded in hardware-notes so it can
    be recognised again:
    ILI9341 driver landscape drawn un-rotated into 240 columns, the
    other 80 are static; R/B swapped
    ST7789, INVON photo negative
    ST7789, RGB order R/B swapped
    both defaults red->yellow, green->magenta, blue->cyan
    Working c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
    [main.cpp]
2026-09-18 Plan: firmware display layer running DEMO_MODE on the panel
    First of three firmware plans (display, data path, app). Ports render.py to
    TFT_eSPI over a lib/core that is unit-tested natively, with theme colours and
    demo scenes generated from the Python so the two cannot drift. Draws in
    320x48 bands because a full frame cannot be allocated on this chip.
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2026-09-18 Port the board model to fixed-size C structs
    [test_main.cpp]
2026-09-18 Generate theme data for the firmware from the Python themes
    Same reasoning as the sprite export: one source of truth, so the simulator
    and the board cannot drift. A pytest now fails if any generated header is
    stale, which also covers src/sprites.h for the first time.
    [test_main.cpp]
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2026-09-19 Plan: the live data path, with the fixtures it will be tested against
    Second of three firmware plans. All the deciding is pure and natively tested:
    NZ time (the host libc gets Pacific/Auckland wrong, so the rules are ours),
    the de-chunker, the AT parsers against captured responses, and the merge from
    snapshot plus now to Board. The device side is one HTTPS client and one fetch
    task on core 0, so the render loop never blocks.
    Probed live while writing it, and recorded in the plan:
    filter[start_hour]=0 -> 400 Invalid Request; valid range is 1..23, so a
    00:00-00:59 departure cannot be fetched at all
    unknown stop code -> 200 {"data":[]}, not 404
    bad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
2026-09-19 Implement Pacific/Auckland ourselves, because the host libc gets it wrong
    Windows' UCRT placed 2026-09-28 12:00 NZDT at 11:00 UTC with the POSIX TZ
    string the spike used. The rules are 40 lines; the values are pinned against
    Python's zoneinfo, including both DST transitions and the GTFS noon-minus-12
    service-day rule that keeps noon at noon when the clocks move.
    [test_main.cpp]
2026-09-19 Port the de-chunker to pure code, with the silent failure as a test
    The spike proved the algorithm on hardware but as an Arduino Stream, which
    cannot be tested natively. Behind a read callback it is testable, and one test
    pins the bug it exists to prevent: the same bytes fed straight to ArduinoJson
    parse as the number 4657 and report success.
    [test_main.cpp]
2026-09-19 Parse the AT APIs against the captured fixtures
    Every parser is exercised through its own ArduinoJson filter, so a filter that
    drops a field the board needs fails a test instead of the board. The awkward
    shapes from docs/at-api-notes.md are pinned: a stop_time_update that is an
    object rather than an array, a bus route with no colour, HUIA's #000000, and
    start_hour=0 which the API rejects outright.
    [test_main.cpp]
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2026-09-19 Talk to AT over TLS pinned to DigiCert Global Root G2
    Pins the root rather than the leaf, which is reissued every six months, and
    never setInsecure(). Splits the build into a live esp32 env and an esp32_demo
    env so the demo stays flashable. The live build resolves both stop codes at
    boot and says so on serial.
    [main.cpp]
2026-09-19 Wait for WiFi and NTP before the AT self-check, and log transport errors
    The live build's boot self-check returned HTTP -1 for both stops on first
    flash: WiFi.begin() is asynchronous, and the fetch ran before association (and
    before NTP) had a chance to complete. setup() now polls WiFi.status() for up
    to 20s (printing status once a second, then the IP/RSSI once connected, or a
    clear failure line) and time(nullptr) for up to 15s before running the stop
    lookups at all; either timeout skips the self-check instead of fetching blind.
    at_get() also now logs WiFiClientSecure::lastError() on a transport failure,
    so a TLS handshake failure is distinguishable from a plain socket failure on
    serial.
    [main.cpp]
2026-09-19 Fetch on core 0 and publish a snapshot the renderer can read
    Every network call lives in one task pinned to the other core, because a TLS
    handshake takes longer than a frame and the board must keep animating (spec 8).
    The task owns the cadences, the backoff and the error surfaces; the render loop
    only ever copies a snapshot.
    The boot self-check goes with it: it did two TLS round-trips on the Arduino
    loop task's 8 KB stack, which is marginal for mbedTLS. setup() now connects
    WiFi, starts NTP and hands over.
    [fetcher.cpp, main.cpp]
2026-09-19 Publish the nominal poll cadence, never the backoff
    poll_interval_s tells the renderer how long a gap between polls is normal, so
    that a healthy two-minute cadence does not read as stale. Publishing the
    backed-off interval instead made a total outage hide itself for longer the
    worse it got - up to ~390 s before the board admitted staleness - which inverts
    spec 8 and is the one failure this project cares most about: stale data that
    does not look stale.
    The backoff still paces the task and still shows in the log; it just no longer
    reaches build_board. The no-link branch was publishing its 5 s retry for the
    same reason and is fixed the same way, so staleness now grows at one rate
    whichever fai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
    [fetcher.cpp]
2026-09-19 Derive direction per route and direction, not per direction alone
    Kingsland is served by two lines and only one reaches Waitemata: E-W goes via
    the city, O-W runs to Onehunga via Newmarket. Taking one candidate trip per
    direction_id asked the wrong trip and concluded that neither direction served
    the target, so the board said "check config" while trains it wanted were due.
    The spec says direction is a property of (route_id, direction_id); now the code
    agrees, and only the rows of a pair proven to reach the target are shown.
    [fetcher.cpp, test_main.cpp]
2026-09-19 Treat an inconclusive refresh as no evidence at all
    A refresh where some trips/{id}/stops probes failed and none of the rest
    served proved nothing, yet it published an empty board, pushed the retry out
    15 minutes and counted as fresh data. Now it keeps the previous state and rows,
    retries in 60 s, logs the failed pair as "err", and does not move last_ok.
    Only a conclusive schedule refresh or a realtime 200 counts as news.
    Also: a pinned watch drops other routes' rows before the pairs are collected,
    so the pair cap can no longer squeeze out its own route, and says so if the cap
    is ever hit. The published interval is when the board next expects news, so a
    quiet night with nothing for realtime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
    [fetcher.cpp]
2026-09-19 Draw the live board: real departures, counting down between polls
    Pace the frame loop against an absolute deadline instead of a relative
    delay, so a slow frame or the 5s report line does not drift the
    average frame rate; if we fall behind, snap the deadline to now
    instead of trying to catch up in one step. Applied to both builds:
    the demo's scene selection is driven by millis() directly, not by
    the pacing code, so tightening the delay math does not change what
    it draws, only how precisely 15 fps is held.
    Read time(nullptr) once per frame and pass it straight through to
    board_now(). Before NTP lands it is some small epoch near 1970, but
    every watch is still WatchState::Starting until the fet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
    [main.cpp]
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2026-09-19 Cite the start_hour=0 fixture and tighten hardware-notes wording
    The 400 detail for filter[start_hour]=0 is now quoted from a saved
    fixture instead of a truncated live probe, plus reword two hardware-notes
    passages the reviewer flagged: state the fetch-task stack's peak-use byte
    arithmetic instead of an unexplained KB figure, and trim the WiFi-association
    note to only what was observed on hardware.
2026-09-19 Fetch after-midnight services from the service date they belong to
    The API was misread. Live on Saturday 2026-09-19 at Kingsland,
    date=2026-09-19&start_hour=23&hour_range=3 returned 19 rows from 23:04 to
    25:25, and start_hour=24 is accepted. After-midnight trains are filed under
    the previous service date as 24:xx and 25:xx; hour_range is not clamped at
    midnight. The old midnight split asked the next date and got nothing.
    url_stoptrips now accepts start_hour 1..47 (0 is still a 400).
    schedule_windows asks one window from 04:00, and in the small hours asks
    yesterday from 24 + hour as well as today from max(hour, 1). The live
    capture is committed as a fixture and at-api-notes says plainly that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
    [fetcher.cpp, test_main.cpp]
2026-09-19 Never let a quiet-night interval un-stale a failing board
    expected_interval was recomputed every pass, news or not. During an outage
    spanning the last departure it jumped from 120 s to 900 s and a visible
    "stale" disappeared for up to about 13 minutes; with WiFi up and the
    internet down, the pass after the last departure makes no request at all,
    so "no failure this pass" could not close it.
    The policy is now pure code in lib/core/freshness, with native tests:
    SCHEDULE_PERIOD_S is published only when nothing is upcoming and nothing
    has failed since the last news, and once anything has failed the published
    interval never grows until news arrives. The fetcher records news and
    failures in the o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
    [fetcher.cpp, test_main.cpp]
2026-09-19 Make the board only as fresh as its stalest schedule
    last_ok was global. If one watch's schedule stayed inconclusive, realtime
    200s for the other watch kept last_ok fresh while the first watch's rows
    ran out, and it ended up saying nothing was due while services ran.
    The fetcher records sched_ok_at per watch, and board_last_ok in lib/core
    publishes the earlier of last_news and the oldest sched_ok_at among Ok
    watches plus SCHEDULE_PERIOD_S. One watch stuck for 40 minutes now makes
    the board stale. Per-watch freshness is left for plan 3.
    [fetcher.cpp, test_main.cpp]
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2026-09-19 Skip blank chunk-size lines in a loop, not by recursion
    Each stray blank line between chunks was one more recursive call to
    ensure(), so a peer sending enough of them could walk the fetch task off
    the end of its 16 KB stack. A run of a million blank lines now overflowed
    the native test's stack (0xC00000FD) before this change and passes after.
    [test_main.cpp]
2026-09-19 Log failed stoptrips, free the JSON doc early, show largest block
    - sched <code>: HTTP <n> for any stoptrips answer but 200 or 404
    - g_doc.clear() straight after every parse_*: each copies out
    - the fetch: line gains pub (the interval published for staleness) and
    largest (heap_caps_get_largest_free_block, 8-bit)
    - the task 7a realtime URL print is gone
    - a 15 s TLS handshake timeout instead of the 120 s default, and a comment
    on why setReuse(false) is required: the de-chunker does not drain the
    trailing CRLF
    [fetcher.cpp]
2026-09-19 Say that esp32 is the live build and needs secrets.h
    The README still said esp32 ran DEMO_MODE. It is the live build; the demo
    is esp32_demo. The demo claim was also wrong: it compiles the network
    sources, so src/secrets.h must exist (an unedited example copy will do).
    hardware-notes drops the frame-rate-with-TLS item, which was measured, and
    the outage check now expects dimmed lanes.
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2026-09-19 Plan the config portal in twelve tasks
    Pure schema logic first, proven under pio test -e native, then the NVS
    wrapper, then the call-site conversion as a behaviour-preserving step,
    then the server one endpoint at a time.
    Seven of the twelve need the board flashed, and each one says so: auto
    reset does not work on this hardware, so a human holds BOOT and taps EN
    before every upload.
2026-09-19 Back the configuration with NVS, seeded from watch_config.h
    config_save_json writes NVS and deliberately leaves the in-RAM config
    alone: the fetch task reads the watches on core 0 without a lock, so the
    new values are picked up by config_begin() after a reboot instead.
    [config.cpp]
2026-09-19 Validate compiled watch defaults through the pure config parser
    seed_from_compiled_defaults() copied watch_config.h with strncpy and hand-set
    enabled=true, bypassing every invariant cfg_parse() enforces on the same
    shape of data - an empty stop_code, an over-long field, or too many watches
    would silently produce a board cfg_parse() would have rejected. Round-trip
    the seeded Config through cfg_serialize()/cfg_parse() and log loudly on
    failure, still booting with the seeded config either way.
    Also relocates the static_assert(N_WATCHES <= MAX_WATCHES) that Task 5
    deletes from src/fetcher.cpp: N_WATCHES is still constexpr and this loop
    still depends on it, so the compile-time guard belongs here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
    [config.cpp]
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2026-09-19 Reject unterminated stop responses and non-alphanumeric stop codes
    serializeJson() only null-terminates when it writes fewer bytes than
    the buffer, so an exact fill or truncation left handle_check_stop
    handing g_server.send() an unterminated array; its const char*
    overload does a strlen-driven copy that would then read past the
    stack buffer and ship whatever followed it. Check the return value
    and fail closed instead.
    Also validate stop_code as ASCII alphanumeric, capped at
    CFG_FIELD_CAP - 1, before it reaches url_stop_by_code(). That helper
    only checks the built URL fits, so unfiltered input could append a
    query parameter or inject CR/LF into a request made with this
    device's API key.
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2026-09-19 Track watch rows by a stable id and stop building theme options via innerHTML
    A check's result used to be written to a <div> captured at click time;
    adding or removing a watch while that check was still in flight rebuilt
    the list and detached the node, so the answer landed nowhere and the user
    saw silence instead of a pass or a failure. Rows now carry a monotonic id,
    and the result is looked up by that id when there is something to show; a
    row that is gone by then is quietly skipped.
    Theme options are now built with createElement/textContent instead of
    concatenating names into innerHTML, closing the one sink in the page that
    did not already reject markup by construction.
2026-09-20 Remove the throwaway spikes and the fixtures they left behind
    Both spikes have answered their question: the heap budget and the
    de-chunker are written up in docs/hardware-notes.md, and the de-chunking
    Stream itself shipped as lib/core/src/dechunk.cpp. The panel spike
    settled ST7789 vs ILI9341. Nothing in src/, lib/ or the build referenced
    either directory.
    Also drops nine fixtures no test loads, five of them pre-CRL files that
    test/fixtures/post-crl/ replaced.
    [main.cpp]
2026-09-20 Add the enclosure: a parametric wedge, its dimensions and how it goes together
    The third-party ESP32-C3 case this build started from cannot take a
    WROOM-32 with ordinary jumper wires at any orientation, which is measured
    in the rework spec. So the case is modelled from scratch instead: a raked
    wedge in OpenSCAD where every dimension is a named constant, printable
    without support.
    models/build/ holds the rendered STLs. They are committed for the same
    reason src/sprites.h is - printing one should not require installing the
    tool that generated it - and tests/test_models.py re-checks the
    clearances the design depends on whenever a constant moves.
    docs/enclosure.md is the dimensions spec sectio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
    [wedge.scad, wedge_body.stl, wedge_cover.stl]
2026-09-20 Get the repo ready to be published
    The README claimed there was no setup portal, which there has been since
    771c2f7 - so the setup section now describes the real thing: find the
    board's IP, open it in a browser, fill in four fields per watch. Adds a
    full build walkthrough in docs/SETUP.md, the parts it takes, and what the
    setup page's fields actually mean.
    platformio.ini no longer hardcodes COM8, which only ever worked on one
    machine. src/watch_config.h says what it is now: the first-boot NVS seed,
    not a stand-in for the portal.
    Adds CI over both test suites and both firmware builds, CONTRIBUTING.md,
    SECURITY.md - which is explicit that the setup page is unauthenticated on
    the LAN by desig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

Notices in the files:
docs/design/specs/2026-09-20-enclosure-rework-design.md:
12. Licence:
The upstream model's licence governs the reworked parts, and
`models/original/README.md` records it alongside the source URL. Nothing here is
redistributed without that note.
